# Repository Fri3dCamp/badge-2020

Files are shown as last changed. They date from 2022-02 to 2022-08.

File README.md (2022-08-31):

# Fri3d Badge 2020

This repository contains the hardware design of the [Fri3d Camp](https://fri3d.be/) badge for 2020 / 2022. The project progress can be followed on our [Hackaday.io](https://hackaday.io/project/169741-fri3d-2022-badge) page.

## Blockdiagram

In order to make the documentation easier to use, we've added the block diagram in this repository.

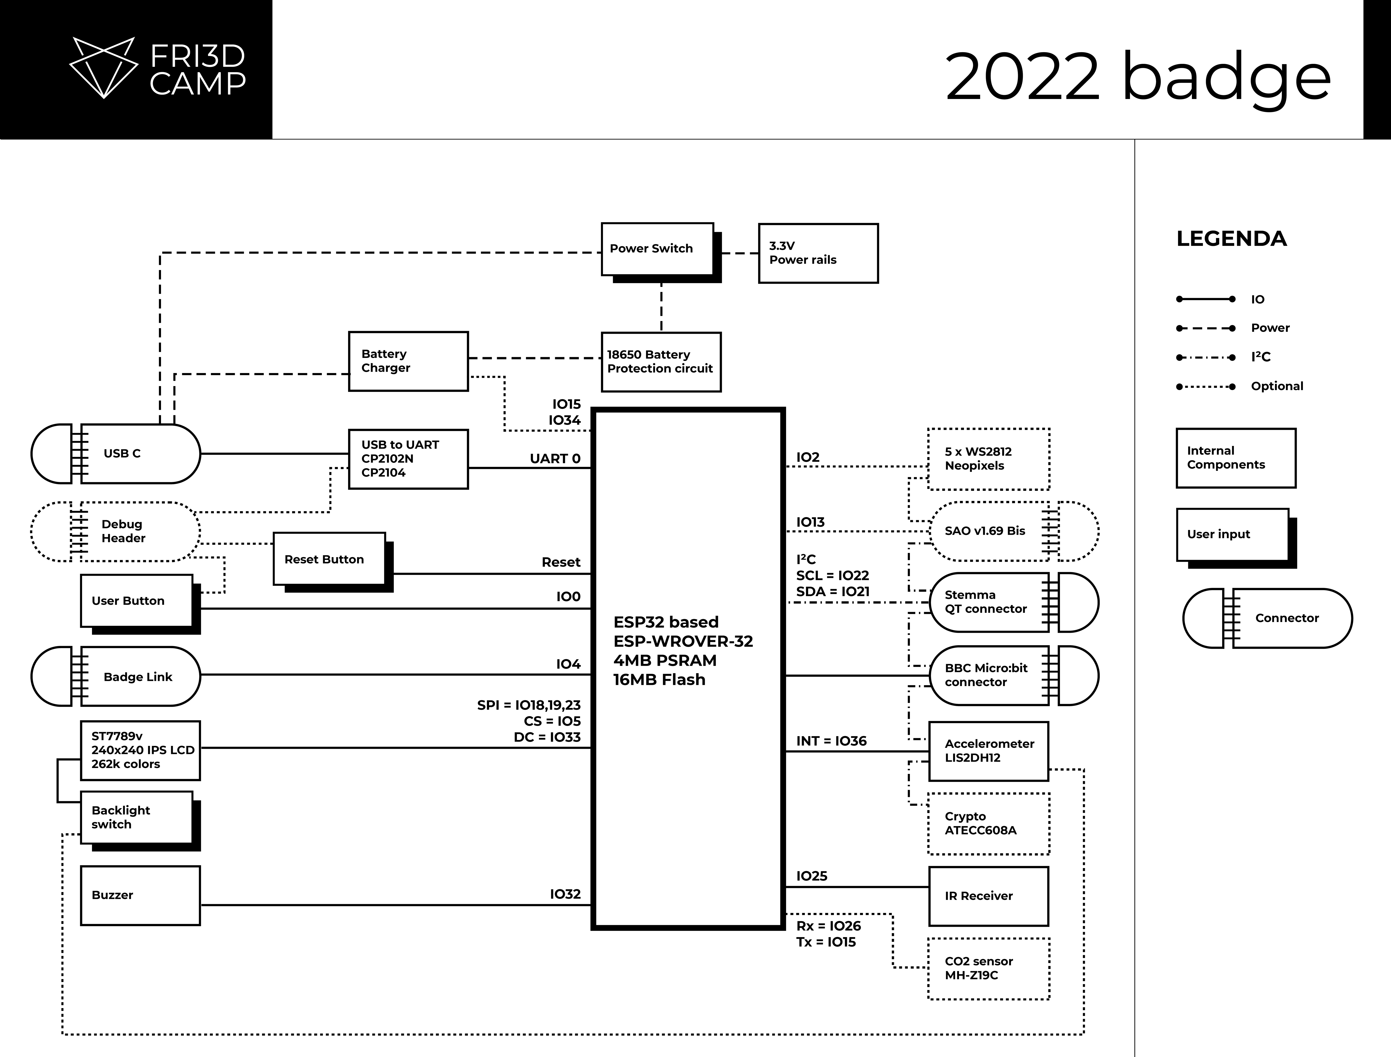
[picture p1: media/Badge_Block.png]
Badge Block Diagram


## REV 00
First prototype to verify the schematic design.

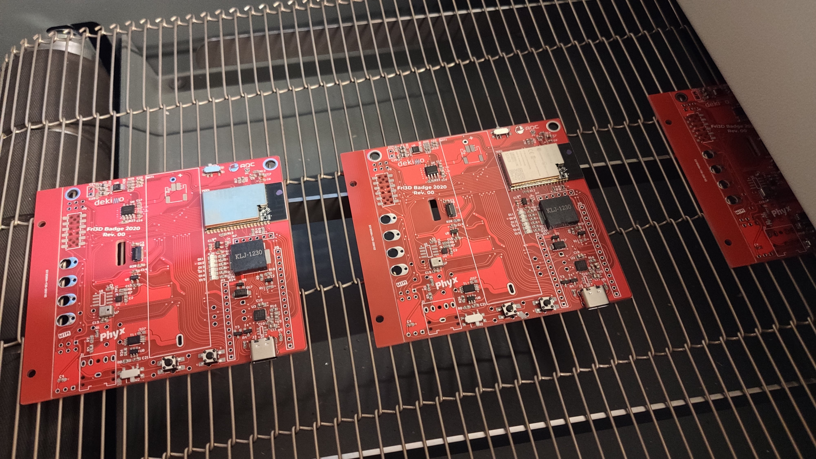
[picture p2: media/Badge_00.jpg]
Badge 00


## REV 01
Moved away from the Adafruit Feather compatible expansion header in favor for the [BBC micro:bit expansion connector](https://tech.microbit.org/hardware/edgeconnector/)

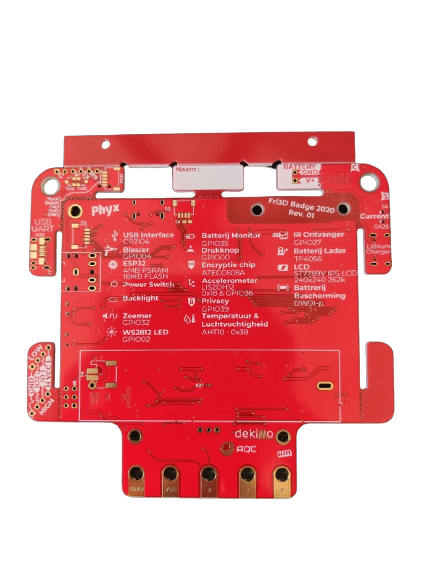
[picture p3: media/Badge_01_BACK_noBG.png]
Badge 01


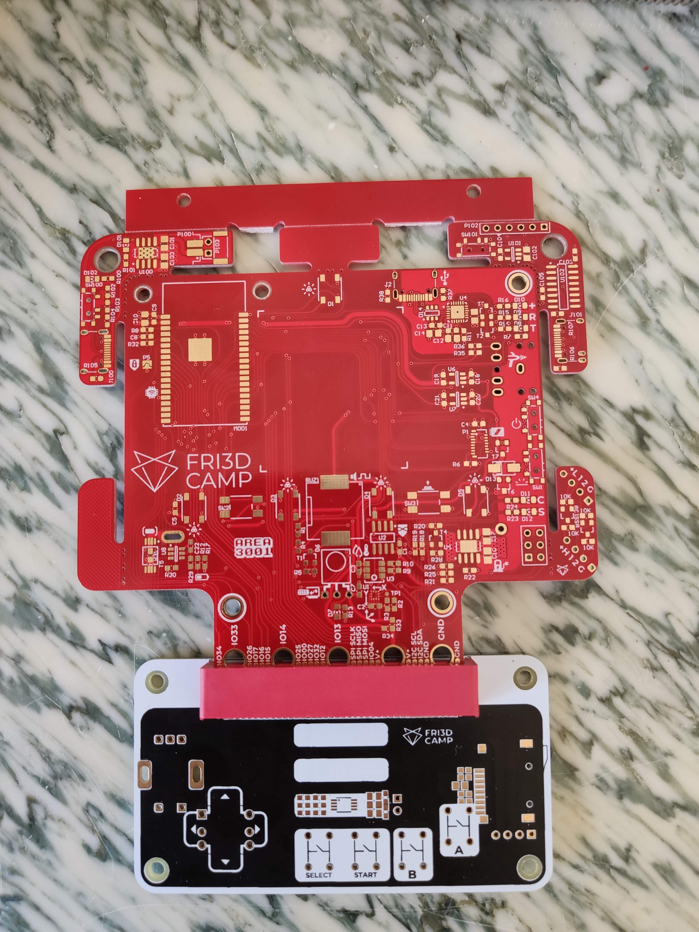
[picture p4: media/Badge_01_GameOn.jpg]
Badge 01 GameOn

Test fit of the badge with the first protoype of the [GameOn](https://github.com/Fri3dCamp/gameon-2020)

## REV 02
Upgraded the micro:bit connector to V2 shape.
This board has the final shape for the badge and has a green soldermask with black silkscreen.

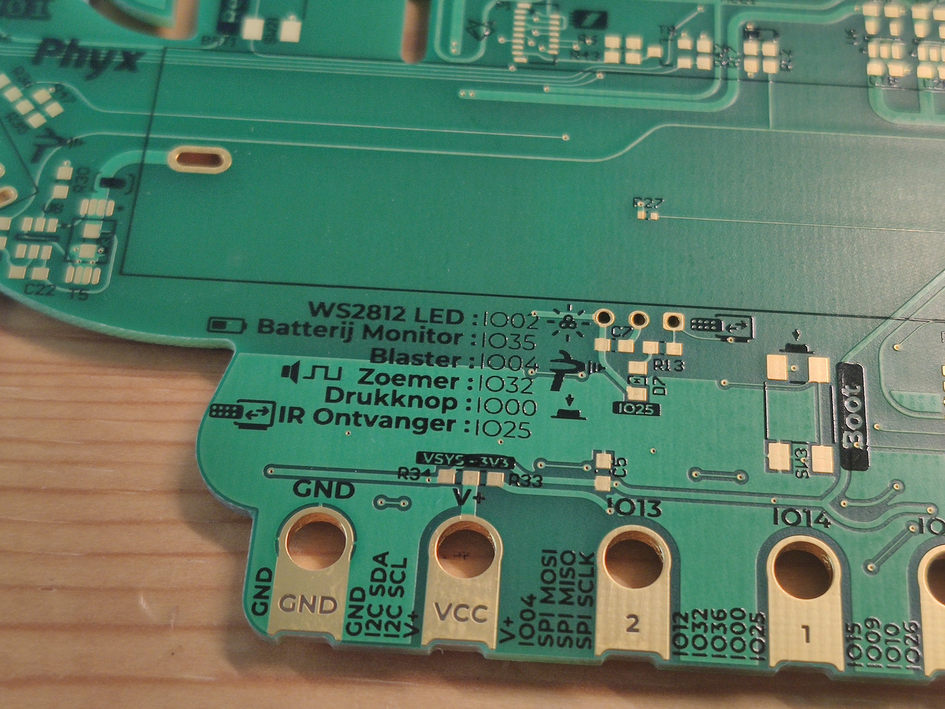
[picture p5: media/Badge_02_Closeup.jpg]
Badge 02 Close up


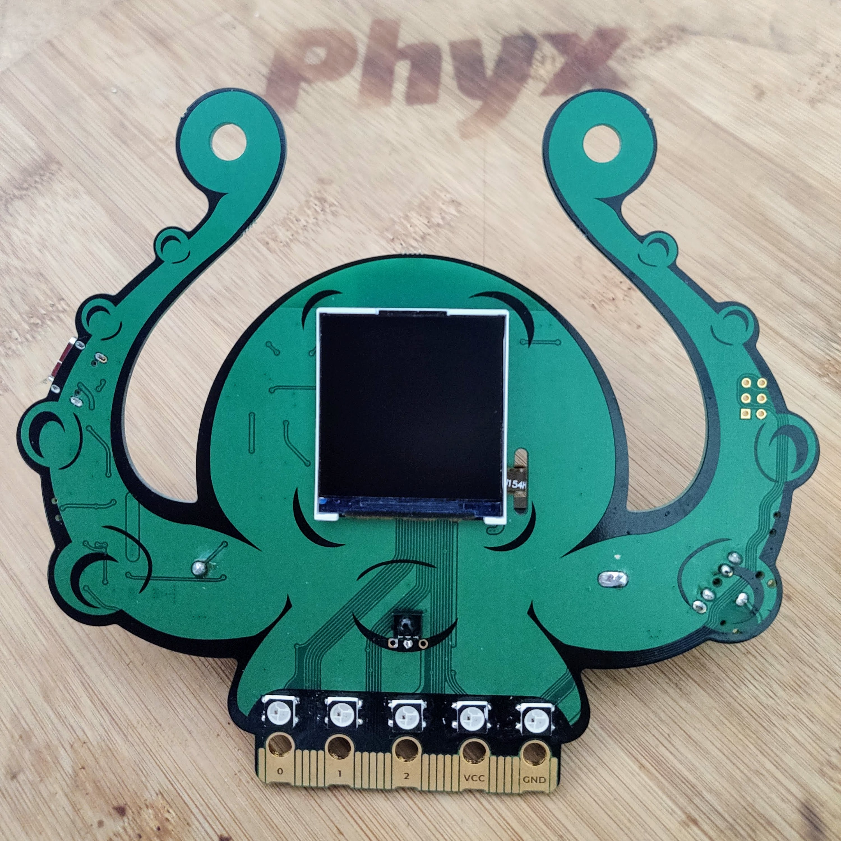
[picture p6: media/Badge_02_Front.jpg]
Badge 02 Close up


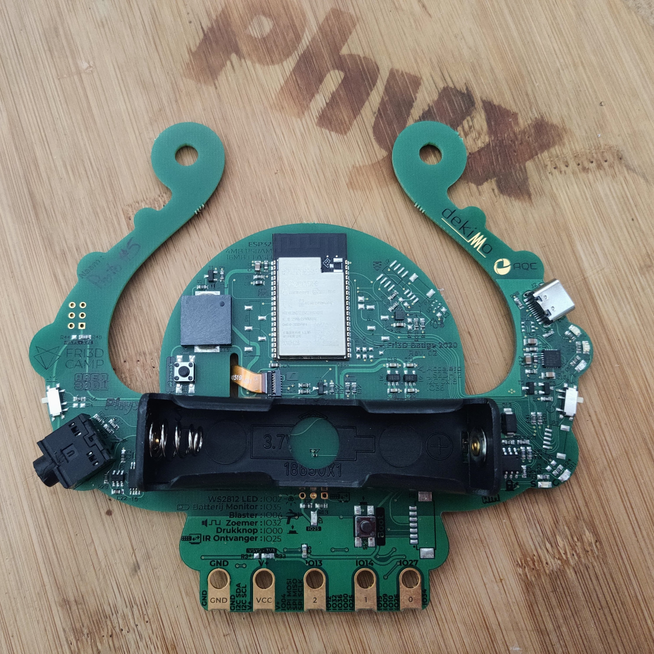
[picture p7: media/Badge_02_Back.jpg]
Badge 02 Close up


## REV 03
The production version of the badge with improvements in the BadgeLink circuit and a change in the LCD backlight button operation. Now the slide switch will either turn the display backlight ON or render it's control to the interrupt pin from the accelerometer allowing for wakeup based on movement for increased battery savings.

## Documentation
In the "media" folder we've added the small infosheet leaflet that's included with the badge as well as the presentation that was given bij Wim Van Gool during the event.

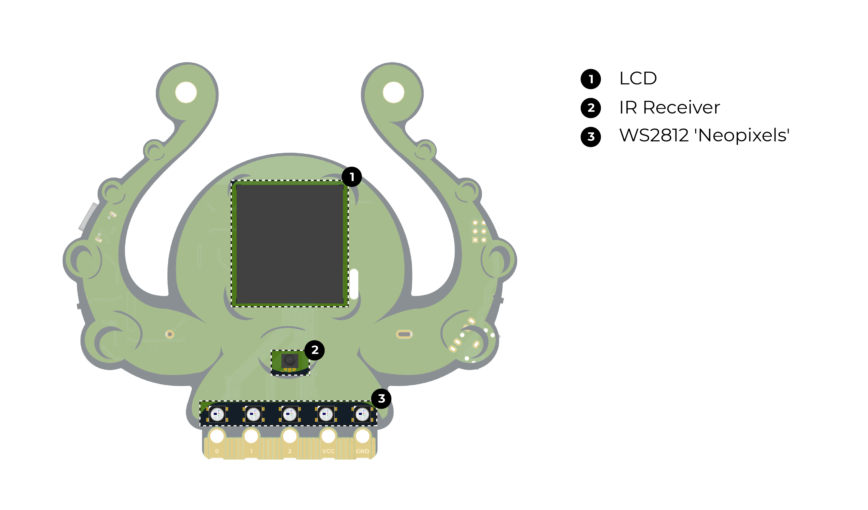
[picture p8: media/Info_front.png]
Badge 03 info front


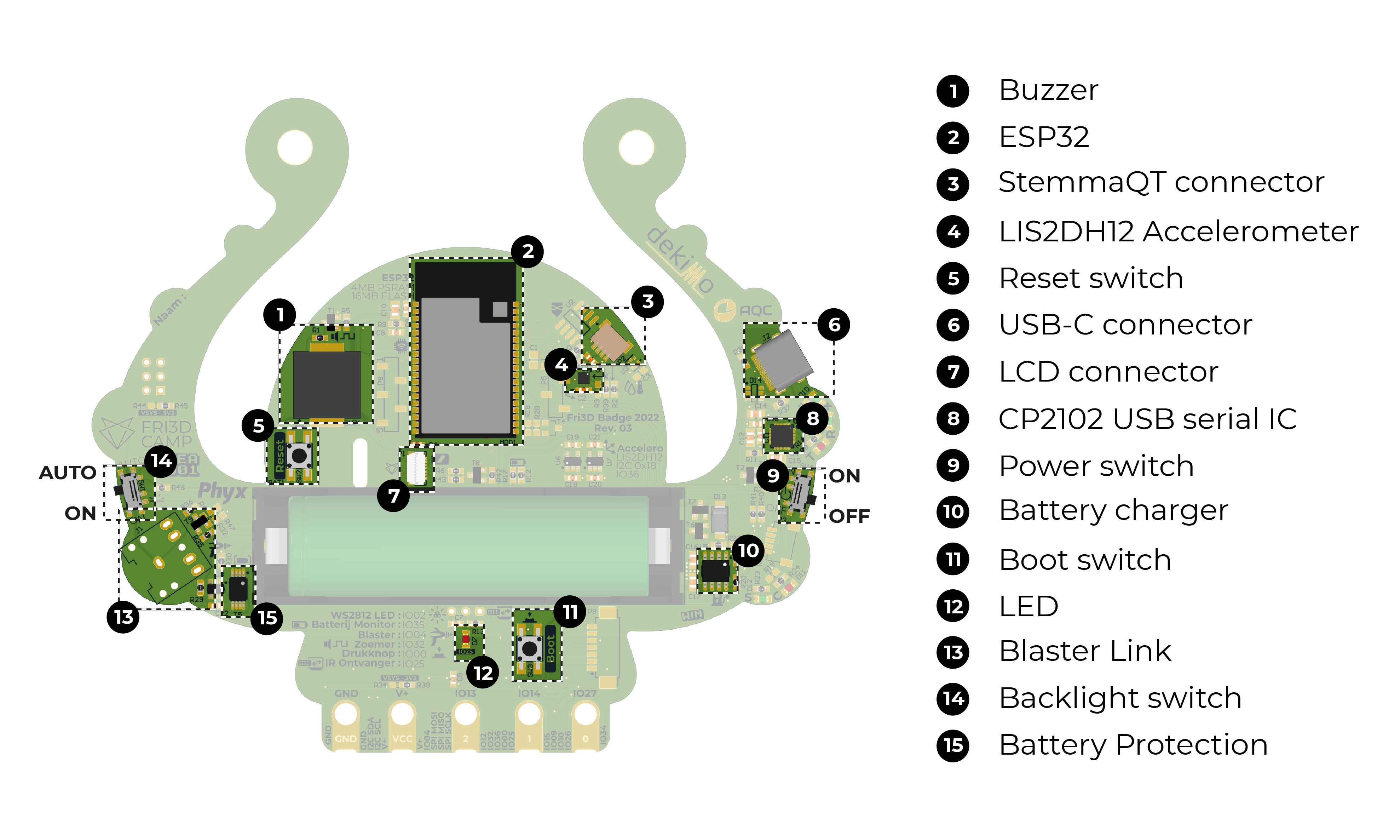
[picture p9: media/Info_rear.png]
Badge 03 info rear


## Hackability

As highlighted in the presentation, the badge has some expansion possibilities.

### CO2 sensor

With the help of P5 and P8 SMD headers [61000413321, 61000513321]( https://www.we-online.com/catalog/en/PHD_2_54_SMT_SOCKET_HEADER_6100XXXXX21) and a 10µF 0805 capacitor, you can add the [MH-Z19C sensor]( https://www.reichelt.com/be/nl/infrarood-co2-sensor-mh-z19c-pin-header-rm-2-54-co2-mh-z19c-ph-p297320.html). Alternatively, there is also room for the [Molex 
53261-0771](https://www.molex.com/molex/products/part-detail/pcb_headers/0532610771) SMD connector on P9 so you can use the [wire mounted variant of the MH-Z19C]( https://www.tinytronics.nl/shop/en/sensors/air/gas/winsen-mh-z19c-co2-sensor-with-cable)
Note that this sensor will only work on 5V so USB power is required. It connects the CO2's serial port to IO26 and IO15 of the ESP32.

### Battery Charger Control

By mounting R18 and R19 with a 100Ω you gain battery charging control. This will allow to read the charger status on GPIO34 and control whether or not the battery should be charging using GPIO15.

### Temperature and Humidity sensor

The [Wurth 2525020210001]( https://www.we-online.com/catalog/en/WSEN-HIDS) temperature and humidity sensor can be mounted on the U3 footprint along with a 100nF 0603 capacitor on C3 for local decoupling.

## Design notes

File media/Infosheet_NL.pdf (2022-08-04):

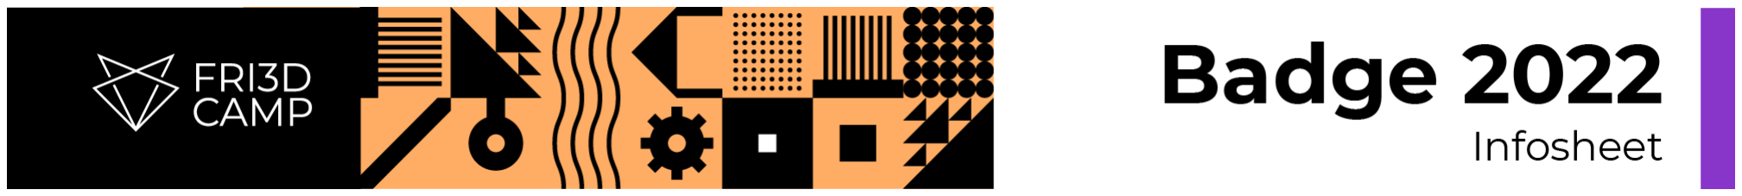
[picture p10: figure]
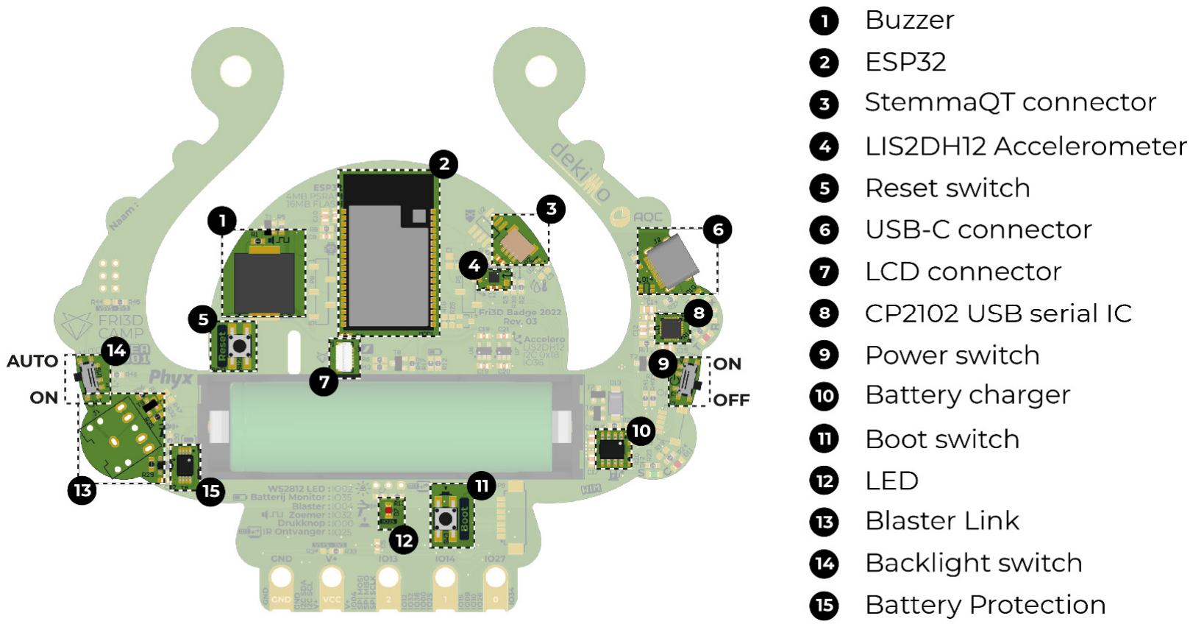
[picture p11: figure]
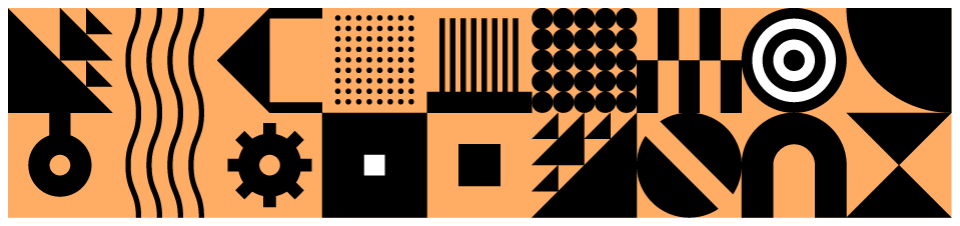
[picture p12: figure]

Wim Van Gool – 20220802 – Badge NL Rev.00 https://github.com/Fri3dCamp/badge-2020https://hackaday.io/project/169741-fri3d-2022-badgehttps://fri3d.be/badge/

Software
De badge is reeds voorzien van software. De meest recente versie kan je steeds terug vinden op https://fri3d.be/badge

Indicatie LEDs
Op de PCB hebben we 5 indicatie-LEDs voorzien: 3 rond het USB-circuit (+, R, T) en 2 bij de batterijlader (S, C).

De “+” geeft aan dat de USB-poort spanning heeft. De “R” en “T” zijn indicatoren voor ontvangen of verzonden data over deze USB.

Voor de batterijlader zijn er groene “S” en rode “C” LEDs. De combinatie van deze 2 LEDs geeft de status weer van de lader.

Status | “C” LED | “S” LED
Batterij is aan het laden | LED aan | LED uit
Batterij is opgeladen | LED uit | LED aan
Temperatuur van de batterij is buiten werkzaam gebied | LED uit | LED uit
Geen batterij aanwezig | LED knippert | LED aan

Overzicht van de functionaliteit

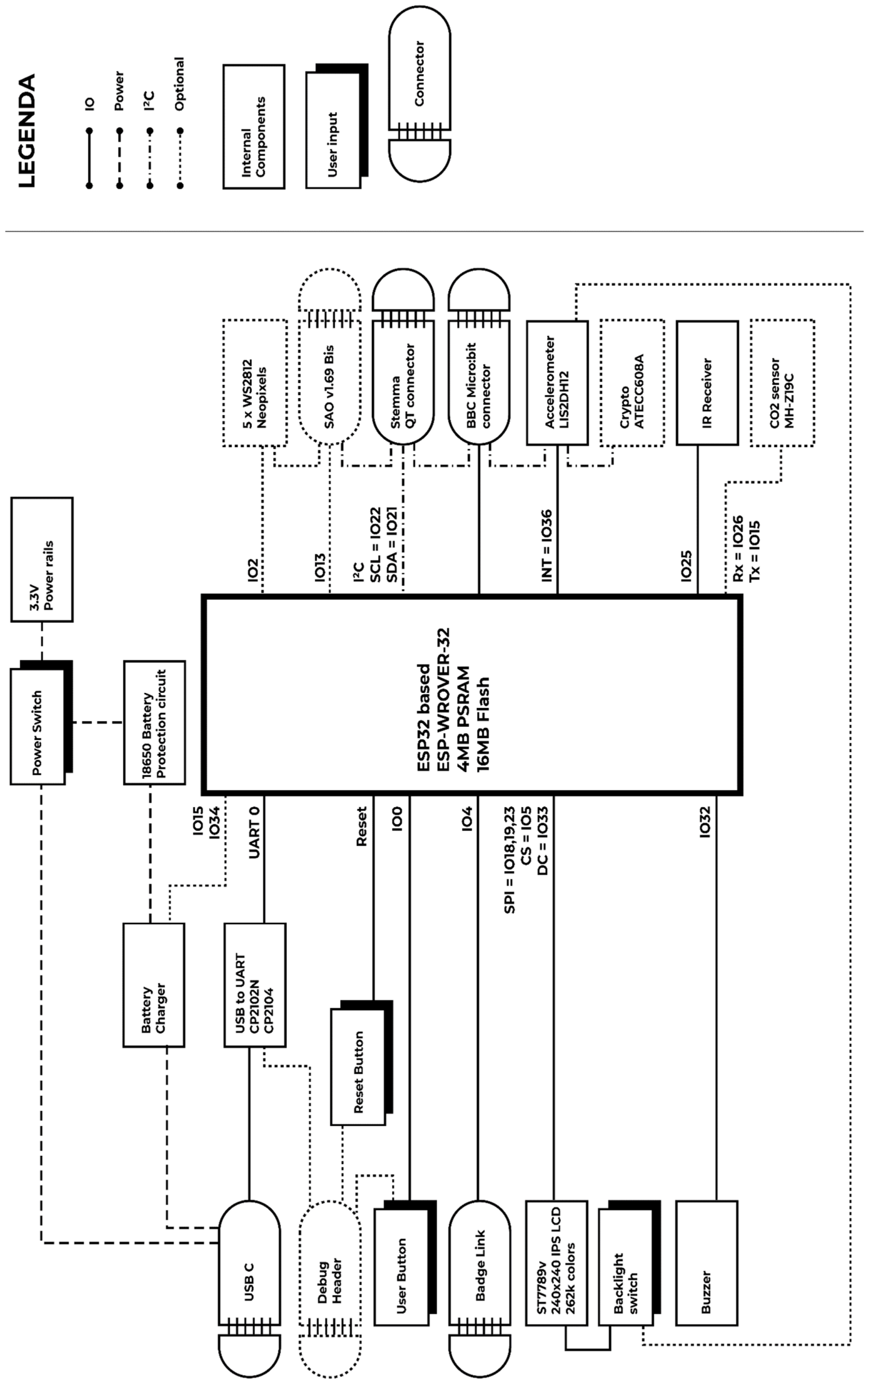
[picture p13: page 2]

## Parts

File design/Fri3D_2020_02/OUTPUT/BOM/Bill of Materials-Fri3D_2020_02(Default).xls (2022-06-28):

Bill of Materials |  |  | Fri3D Badge 2020
Project: |  | Fri3D_2020_02.PrjPcb
Revision: |  | 02
Variant: |  | Default
Creation Date: | 07/01/2022 | 23:19
Print Date: | 2022-03-08 | 14:14:21
Footprint | Comment | LibRef | Designator | Value | Description | Supplier 1 | Supplier Part Number 1 | Supplier 2 | Supplier Part Number 2 | Supplier 3 | Supplier Part Number 3 | Quantity | 750 | 2020-01-26 | order?
BAT_18650_SPRING | 18650 Battery holder with spring | 18650 Battery holder spring CN | BAT1 | 18650_SPRING | 18650 Battery holder spring CN | TaoBao | 39761834568 |  |  |  |  | 1 | 750 | 750 | 0 | LETOP!
CUI_CMT-1203-SMT | 12x12x3mm Piezo Buzzer Transducer 81dB | BUZ # CUI CMT-1203-SMT | BUZ1 | CMT-1203-SMT | BUZ # CUI CMT-1203-SMT | Digi-key | 102-2197-1-ND | LCSC | C409829 | LCSC | C391037 | 1 | 750 | 750 | 0 | LETOP!
C0603_N |  | CAP # 100nF 16V 0603 | C2, C4, C7, C8, C9, C11, C13, C22 | 100nF 16V | CAP # 100nF 16V 0603 | LCSC | C282519 |  |  | Generic | 100nF 16V 0603 X7R | 8 | 6000 | 12000 | 0
C0603_N |  | CAP # 1uF 16V 0603 | C5, C18, C19, C20, C21 | 1uF 16V | CAP # 1uF 16V 0603 | Farnell | 2320814 |  |  | Generic | 1uF 16V 0603 X7R | 5 | 3750 | 8000 | 0
C0805_N |  | CAP # 10uF 10V 0805 | C10, C12, C14, C15, C16, C17 | 10uF 10V | CAP # 10uF 10V 0805 | Farnell | 2320859 | LCSC | C17024 | Generic | 10uF 10V 0805 X7R | 6 | 4500 | 6000 | 0
LED_5050_WS2812B_BLACK | WS2812 based digital RGB LED 5050 Black package | LED # RGB WS2812B-5050 BL | D1, D2, D3, D4, D5 | WS218B 5050 BL | LED # RGB WS2812B-5050 BL | Aliexpress | WS2812B Black 5050 | LCSC | C114586 |  |  | 5 | 3750 | 6000 | 0
VIS_TSOP381x_BENT | IRM-3638N3F14 Infrared Receiver 38 kHz 45° 2.7-5.5V | PHO IR Rx RA | D6 | IRM-3638N3F14 | PHO IR Rx RA | LCSC | C264262 |  |  |  |  | 1 | 750 |  | 750 | LETOP!
LED_0805_RD | Default 0805 Red LED | LED # Red 0805 | D7, D8, D11 |  | LED # Red 0805 | Farnell | 2099236 |  |  |  |  | 3 | 2250 | 3000 | 0
LED_0805_GR | Default 0805 Green LED | LED # Green 0805 | D9, D10, D12 |  | LED # Green 0805 | Farnell | 2099239 |  |  |  |  | 3 | 2250 | 3000 | 0
SMA_AC | MBRA210LT3G Schottky Power Rectifier, 2A, 10V | Schottky # MBRA210LT3G | D13 | MBRA210LT3G | Schottky # MBRA210LT3G | LCSC | C145190 |  |  |  |  | 1 | 750 | 800 | 0
HRO_TYPE-C-31-M-12 | USB 2.0 C Reversible Receptacle Horizontal | USB # C 2.0 RCPT TYPE-C-31-M-12 | J2 | TYPE-C-31-M-12 | USB # C 2.0 RCPT TYPE-C-31-M-12 | China | HRO TYPE-C-31-M-12 | LCSC | C165948 | LCSC ALT | C167321 / C319148 | 1 | 750 | 1000 | 0
ESP-WROVER-32 | ESP-32 based ESP-WROVER-32 | WiFi # MOD ESP-WROVER-32 | MOD1 | ESP-WROVER-32 | WiFi # MOD ESP-WROVER-32 | Espressif | ESP-WROVER-32 |  |  |  |  | 1 | 750 | 800 | 0
FPC_AFE03-S15FMA-1H | Bottom contact FPC 0.3mm pitch 15 contacts | FPC # 15 Bottom 0.3mm AFE03-S15FMA-1H | P1 | AFE03-S15FMA-1H | FPC # 15 Bottom 0.3mm AFE03-S15FMA-1H | LCSC | C262541 |  |  |  |  | 1 | 750 | 800 | 0
MicroBIT_V2_PCB | MicroBit PCB connector | MicroBit # PCB part | P7 |  | MicroBit # PCB part | NO PART |  |  |  |  |  | 1 | 750 | 10000 | 0
R0603_N |  | RES # 1K2 0603 | R1, R11, R13, R14, R15, R16, R22, R23, R24, R30 | 1K2 | RES # 1K2 0603 | Farnell | 2446592 |  |  | Generic | 1K2 1% 0603 | 10 | 7500 | 10000 | 0
R0603_N |  | RES # 100K 0603 | R2, R5, R12, R17, R25, R26, R42 | 100K | RES # 100K 0603 |  |  |  |  | Generic | 100K 1% 0603 | 7 | 5250 |  | 5250 | LETOP!
R0603_N |  | RES # 100R 0603 | R6, R29, R39, R40, R41, R43, R46 | 100R | RES # 100R 0603 | Farnell | 2446544 |  |  | Generic | 100R 1% 0603 | 7 | 5250 | 5000 | 250 | LETOP!
R0603_N |  | RES # 5K1 0603 | R7, R8, R9, R10, R20, R21, R35, R36, R37, R38, R47 | 5K1 | RES # 5K1 0603 | Farnell | 2845922 | LCSC | C112314 | Generic | 5K1 1% 0603 | 11 | 8250 | 10000 | 0
R0402 |  | NTC # 10K 0402 | R27 | 10K | NTC # 10K 0402 | LCSC | C209959 | LCSC | C98099 |  |  | 1 | 750 |  | 750 | LETOP!
R0603_N |  | RES # 0R 0603 | R33, R45 | 0R | RES # 0R 0603 | Farnell | 2447743 | LCSC | 5000 | Generic | 0R 1% 0603 | 2 | 1500 |  | 1500 | LETOP!
WE_450404015514 | WS-SLSU Mini slide switch 1P2T SMD | SW # 1P2T WS-SLSU mini slide 6,7 x 2,7 mm | SW1, SW4 | 450404015514 | SW # 1P2T WS-SLSU mini slide 6,7 x 2,7 mm | Digi-key | 732-13665-1-ND | LCSC | C431540 |  |  | 2 | 1500 | 3000 | 0
WE_430181038816 | 4.5x4.5mm tact SMD H3,8mm | SW # TACT small 4.5x4.5mm SMD WS-TASV | SW2, SW3 | 430181038816 | SW # TACT small 4.5x4.5mm SMD WS-TASV | Wurth | 430181038816 | Mouser | 710-430181038816 | LCSC | C174049 | 2 | 1500 | 2000 | 0
SOT23-3 | 0.2A N-Ch MOSFET Vgs 3.2 | BSS138 N-Ch MOSFET 0.2A 3.2Vgs 60Vds | T1, T2, T3, T8 | BSS138 | BSS138 N-Ch MOSFET 0.2A 3.2Vgs 60Vds | Farnell | 2432717 | LCSC | C426569 |  |  | 4 | 3000 | 3000 | 0 | LETOP!
TSSOP_8_65P | Dual N-Ch MOSFET Common Drain | FS8205A Dual N-Ch common Drain for DW01-P | T5 | FS8205A | FS8205A Dual N-Ch common Drain for DW01-P | AliExpress | FS8205A | LCSC | C16052 |  |  | 1 | 750 | 800 | 0
SOT23-3 | -2.3A -20V P-Ch MOSFET Vgs -1V | SL2301 P-Ch MOSFET -2.3A -20Vds | T6, T7 | SL2301 | SL2301 P-Ch MOSFET -2.3A -20Vds | LCSC | C181086 |  |  |  |  | 2 | 1500 | 800 | 700 | LETOP!
STM_LGA12_2x2 | 3-Axis, ±2 g/±4 g/±8 g/±16 g Digital Accelerometer | ACCELERO # LIS2DH12 | U1 | LIS2DH12 | ACCELERO # LIS2DH12 | LCSC | C110926 |  |  |  |  | 1 | 750 | 800 | 0
QFN_24 | USB to UART 3.3-5V | CP2102N # QFN24 USB UART | U4 | CP2102N-A01-GQFN24 | CP2102N # QFN24 USB UART | Farnell | 2577278 | Digi-key | 336-3693-ND |  |  | 1 | 750 | 800 | 0
SOIC_N_8_TH | Single Cell LiIon charger max 1A | CHG # TP4056 LiIon 1A | U5 | TP4056 | CHG # TP4056 LiIon 1A | Aliexpress | TP4056 | LCSC | C382139 |  |  | 1 | 750 | 800 | 0
SOT23-5 | 3V3 LDO 700mA 50mV | LDO # 3V3 XC6210B33 | U6, U7 | XC6210B332MR | LDO # 3V3 XC6210B33 | Farnell | 1057803 | LCSC | C47719 |  |  | 2 | 1500 | 3000 | 0
SOT23-6 | DW01-P single cell lithium protection | PWR # DW01-P Lithium protection | U8 | DW01-P | PWR # DW01-P Lithium protection | Aliexpress | DW01-P | LCSC | C181096 |  |  | 1 | 750 | 800 | 0
 |  |  |  |  |  |  |  |  |  |  |  | 93
Approved |  | Notes

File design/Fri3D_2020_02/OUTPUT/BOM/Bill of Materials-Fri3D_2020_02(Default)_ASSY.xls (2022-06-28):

Bill of Materials |  | Fri3D Badge 2020
Project: | Fri3D_2020_02.PrjPcb
Revision: | 02
Variant: | Default
Footprint | LibRef | Designator | Value | Description | Qty | x10 | Location
BAT_18650_SPRING | 18650 Battery holder spring CN | BAT1 | 18650_SPRING | 18650 Battery holder spring CN | 1 | 10
CUI_CMT-1203-SMT | BUZ # CUI CMT-1203-SMT | BUZ1 | CMT-1203-SMT | BUZ # CUI CMT-1203-SMT | 1 | 10
C0603_N | CAP # 100nF 16V 0603 | C2, C4, C7, C8, C9, C11, C13, C22 | 100nF 16V | CAP # 100nF 16V 0603 | 8 | 80
C0603_N | CAP # 1uF 16V 0603 | C5, C18, C19, C20, C21 | 1uF 16V | CAP # 1uF 16V 0603 | 5 | 50
C0805_N | CAP # 10uF 10V 0805 | C10, C12, C14, C15, C16, C17 | 10uF 10V | CAP # 10uF 10V 0805 | 6 | 60
LED_5050_WS2812B_BLACK | LED # RGB WS2812B-5050 BL | D1, D2, D3, D4, D5 | WS218B 5050 BL | LED # RGB WS2812B-5050 BL | 5 | 50
VIS_TSOP381x_BENT | PHO IR Rx RA | D6 | IRM-3638N3F14 | PHO IR Rx RA | 1 | 10
LED_0805_RD | LED # Red 0805 | D7, D8, D11 |  | LED # Red 0805 | 3 | 30
LED_0805_GR | LED # Green 0805 | D9, D10, D12 |  | LED # Green 0805 | 3 | 30
SMA_AC | Schottky # MBRA210LT3G | D13 | MBRA210LT3G | Schottky # MBRA210LT3G | 1 | 10
HRO_TYPE-C-31-M-12 | USB # C 2.0 RCPT TYPE-C-31-M-12 | J2 | TYPE-C-31-M-12 | USB # C 2.0 RCPT TYPE-C-31-M-12 | 1 | 10
ESP-WROVER-32 | WiFi # MOD ESP-WROVER-32 | MOD1 | ESP-WROVER-32 | WiFi # MOD ESP-WROVER-32 | 1 | 10
FPC_AFE03-S15FMA-1H | FPC # 15 Bottom 0.3mm AFE03-S15FMA-1H | P1 | AFE03-S15FMA-1H | FPC # 15 Bottom 0.3mm AFE03-S15FMA-1H | 1 | 10
MicroBIT_V2_PCB | MicroBit # PCB part | P7 |  | MicroBit # PCB part | 1 | 10
R0603_N | RES # 1K2 0603 | R1, R11, R13, R14, R15, R16, R22, R23, R24, R30 | 1K2 | RES # 1K2 0603 | 10 | 100
R0603_N | RES # 100K 0603 | R2, R5, R12, R17, R25, R26, R42 | 100K | RES # 100K 0603 | 7 | 70
R0603_N | RES # 100R 0603 | R6, R29, R39, R40, R41, R43, R46 | 100R | RES # 100R 0603 | 7 | 70
R0603_N | RES # 5K1 0603 | R7, R8, R9, R10, R20, R21, R35, R36, R37, R38, R47 | 5K1 | RES # 5K1 0603 | 11 | 110
R0402 | NTC # 10K 0402 | R27 | 10K | NTC # 10K 0402 | 1 | 10
R0603_N | RES # 0R 0603 | R33, R45 | 0R | RES # 0R 0603 | 2 | 20
WE_450404015514 | SW # 1P2T WS-SLSU mini slide 6,7 x 2,7 mm | SW1, SW4 | 450404015514 | SW # 1P2T WS-SLSU mini slide 6,7 x 2,7 mm | 2 | 20
WE_430181038816 | SW # TACT small 4.5x4.5mm SMD WS-TASV | SW2, SW3 | 430181038816 | SW # TACT small 4.5x4.5mm SMD WS-TASV | 2 | 20
SOT23-3 | BSS138 N-Ch MOSFET 0.2A 3.2Vgs 60Vds | T1, T2, T3, T8 | BSS138 | BSS138 N-Ch MOSFET 0.2A 3.2Vgs 60Vds | 4 | 40
TSSOP_8_65P | FS8205A Dual N-Ch common Drain for DW01-P | T5 | FS8205A | FS8205A Dual N-Ch common Drain for DW01-P | 1 | 10
SOT23-3 | SL2301 P-Ch MOSFET -2.3A -20Vds | T6, T7 | SL2301 | SL2301 P-Ch MOSFET -2.3A -20Vds | 2 | 20
STM_LGA12_2x2 | ACCELERO # LIS2DH12 | U1 | LIS2DH12 | ACCELERO # LIS2DH12 | 1 | 10
QFN_24 | CP2102N # QFN24 USB UART | U4 | CP2102N-A01-GQFN24 | CP2102N # QFN24 USB UART | 1 | 10
SOIC_N_8_TH | CHG # TP4056 LiIon 1A | U5 | TP4056 | CHG # TP4056 LiIon 1A | 1 | 10
SOT23-5 | LDO # 3V3 XC6210B33 | U6, U7 | XC6210B332MR | LDO # 3V3 XC6210B33 | 2 | 20
SOT23-6 | PWR # DW01-P Lithium protection | U8 | DW01-P | PWR # DW01-P Lithium protection | 1 | 10
 |  |  |  |  | 93 | 930
Approved | Notes

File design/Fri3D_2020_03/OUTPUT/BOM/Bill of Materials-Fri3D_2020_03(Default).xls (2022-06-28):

Bill of Materials |  |  | Fri3D Badge 2022
Project: |  | Fri3D_2020_03.PrjPcb
Revision: |  | 03
Variant: |  | Default
Creation Date: | 06/06/2022 | 20:56
Print Date: | 2022-06-10 | 20:35:48
Footprint | Comment | LibRef | Designator | Value | Description | Supplier 1 | Supplier Part Number 1 | Supplier 2 | Supplier Part Number 2 | Supplier 3 | Supplier Part Number 3 | Quantity | 750
BAT_18650_SPRING | 18650 Battery holder with spring | 18650 Battery holder spring CN | BAT1 | 18650_SPRING | 18650 Battery holder spring CN | TaoBao | 39761834568 |  |  |  |  | 1 | 750
CUI_CMT-1203-SMT | 12x12x3mm Piezo Buzzer Transducer 81dB | BUZ # CUI CMT-1203-SMT | BUZ1 | CMT-1203-SMT | BUZ # CUI CMT-1203-SMT | Digi-key | 102-2197-1-ND | LCSC | C409829 | LCSC | C391037 | 1 | 750
C0603_N |  | CAP # 100nF 16V 0603 | C2, C4, C6, C7, C8, C9, C11, C13, C22 | 100nF 16V | CAP # 100nF 16V 0603 | LCSC | C282519 |  |  | Generic | 100nF 16V 0603 X7R | 9 | 6750
C0603_N |  | CAP # 1uF 16V 0603 | C5, C18, C19, C20, C21 | 1uF 16V | CAP # 1uF 16V 0603 | Farnell | 2320814 |  |  | Generic | 1uF 16V 0603 X7R | 5 | 3750
C0805_N |  | CAP # 10uF 10V 0805 | C10, C12, C14, C15, C16, C17 | 10uF 10V | CAP # 10uF 10V 0805 | Farnell | 2320859 | LCSC | C17024 | Generic | 10uF 10V 0805 X7R | 6 | 4500
LED_5050_WS2812B_BLACK | WS2812 based digital RGB LED 5050 Black package | LED # RGB WS2812B-5050 BL | D1, D2, D3, D4, D5 | WS218B 5050 BL | LED # RGB WS2812B-5050 BL | Aliexpress | WS2812B Black 5050 | LCSC | C114586 |  |  | 5 | 3750
LED_0805_RD | Default 0805 Red LED | LED # Red 0805 | D7, D8, D11 |  | LED # Red 0805 | Farnell | 2099236 |  |  |  |  | 3 | 2250
LED_0805_GR | Default 0805 Green LED | LED # Green 0805 | D9, D10, D12 |  | LED # Green 0805 | Farnell | 2099239 |  |  |  |  | 3 | 2250
SMA_AC | MBRA210LT3G Schottky Power Rectifier, 2A, 10V | Schottky # MBRA210LT3G | D13 | MBRA210LT3G | Schottky # MBRA210LT3G | LCSC | C145190 |  |  |  |  | 1 | 750
CHAU_ZIRM-5042B-42-Z2 | ZIRM-5042B-42-Z2 Infrared Receiver 38 kHz 45° 2.7-5.5V 940nm | PHO # IR Rx 940nm ZIRM-5042B-42-Z2 | D15 | ZIRM-5042B-42-Z2 | PHO # IR Rx 940nm ZIRM-5042B-42-Z2 | LCSC | C575386 |  |  |  |  | 1 | 750
HRO_TYPE-C-31-M-12 | USB 2.0 C Reversible Receptacle Horizontal | USB # C 2.0 RCPT TYPE-C-31-M-12 | J2 | TYPE-C-31-M-12 | USB # C 2.0 RCPT TYPE-C-31-M-12 | China | HRO TYPE-C-31-M-12 | LCSC | C165948 | LCSC ALT | C167321 / C319148 | 1 | 750
ESP-WROVER-32 | ESP-32 based ESP-WROVER-32 | WiFi # MOD ESP-WROVER-32 | MOD1 | ESP-WROVER-32 | WiFi # MOD ESP-WROVER-32 | Espressif | ESP-WROVER-32 |  |  |  |  | 1 | 750
FPC_AFE03-S15FMA-1H | Bottom contact FPC 0.3mm pitch 15 contacts | FPC # 15 Bottom 0.3mm AFE03-S15FMA-1H | P1 | AFE03-S15FMA-1H | FPC # 15 Bottom 0.3mm AFE03-S15FMA-1H | LCSC | C262541 |  |  |  |  | 1 | 750
WE_665104131822 | Header 1.0mm RA Shrouded 4 | HDR # RA SHR 1.0mm 4way - 665104131822 | P2 | 665104131822 | HDR # RA SHR 1.0mm 4way - 665104131822 | Wurth | 665104131822 | Mouser | 710-665104131822 |  |  | 1 | 750
MicroBIT_V2_PCB | MicroBit PCB connector | MicroBit # PCB part | P7 |  | MicroBit # PCB part | NO PART |  |  |  |  |  | 1 | 750
R0603_N |  | RES # 1K2 0603 | R1, R11, R13, R14, R15, R16, R22, R23, R24, R30 | 1K2 | RES # 1K2 0603 | Farnell | 2446592 |  |  | Generic | 1K2 1% 0603 | 10 | 7500
R0603_N |  | RES # 5K1 0603 | R2, R7, R8, R9, R10, R20, R21, R35, R36, R37, R38 | 5K1 | RES # 5K1 0603 | Farnell | 2845922 | LCSC | C112314 | Generic | 5K1 1% 0603 | 11 | 8250
R0603_N |  | RES # 100K 0603 | R5, R12, R17, R25, R26, R42 | 100K | RES # 100K 0603 |  |  |  |  | Generic | 100K 1% 0603 | 6 | 4500
R0603_N |  | RES # 100R 0603 | R6, R29, R39, R40, R41, R43, R46 | 100R | RES # 100R 0603 | Farnell | 2446544 |  |  | Generic | 100R 1% 0603 | 7 | 5250
R0402 |  | NTC # 10K 0402 | R27 | 10K | NTC # 10K 0402 | LCSC | C209959 | LCSC | C98099 |  |  | 1 | 750
R0603_N |  | RES # 0R 0603 | R33, R45 | 0R | RES # 0R 0603 | Farnell | 2447743 | LCSC | C95177 | Generic | 0R 1% 0603 | 2 | 1500
WE_450404015514 | WS-SLSU Mini slide switch 1P2T SMD | SW # 1P2T WS-SLSU mini slide 6,7 x 2,7 mm | SW1, SW4 | 450404015514 | SW # 1P2T WS-SLSU mini slide 6,7 x 2,7 mm | Digi-key | 732-13665-1-ND | LCSC | C431540 |  |  | 2 | 1500
WE_430181038816 | 4.5x4.5mm tact SMD H3,8mm | SW # TACT small 4.5x4.5mm SMD WS-TASV | SW2, SW3 | 430181038816 | SW # TACT small 4.5x4.5mm SMD WS-TASV | Wurth | 430181038816 | Mouser | 710-430181038816 | LCSC | C174049 | 2 | 1500
SOT23-3 | 0.2A N-Ch MOSFET Vgs 3.2 | BSS138 N-Ch MOSFET 0.2A 3.2Vgs 60Vds | T1, T2, T3, T8, T9 | BSS138 | BSS138 N-Ch MOSFET 0.2A 3.2Vgs 60Vds | Farnell | 2432717 | LCSC | C426569 |  |  | 5 | 3750
TSSOP_8_65P | Dual N-Ch MOSFET Common Drain | FS8205A Dual N-Ch common Drain for DW01-P | T5 | FS8205A | FS8205A Dual N-Ch common Drain for DW01-P | AliExpress | FS8205A | LCSC | C16052 |  |  | 1 | 750
SOT23-3 | -2.3A -20V P-Ch MOSFET Vgs -1V | SL2301 P-Ch MOSFET -2.3A -20Vds | T6, T7 | SL2301 | SL2301 P-Ch MOSFET -2.3A -20Vds | LCSC | C181086 |  |  |  |  | 2 | 1500
STM_LGA12_2x2 | 3-Axis, ±2 g/±4 g/±8 g/±16 g Digital Accelerometer | ACCELERO # LIS2DH12 | U1 | LIS2DH12 | ACCELERO # LIS2DH12 | LCSC | C110926 |  |  |  |  | 1 | 750
QFN_24 | USB to UART 3.3-5V | CP2102N # QFN24 USB UART | U4 | CP2102N-A01-GQFN24 | CP2102N # QFN24 USB UART | Farnell | 2577278 | Digi-key | 336-3693-ND |  |  | 1 | 750
SOIC_N_8_TH | Single Cell LiIon charger max 1A | CHG # TP4056 LiIon 1A | U5 | TP4056 | CHG # TP4056 LiIon 1A | Aliexpress | TP4056 | LCSC | C382139 |  |  | 1 | 750
SOT23-5 | 3V3 LDO 700mA 50mV | LDO # 3V3 XC6210B33 | U6, U7 | XC6210B332MR | LDO # 3V3 XC6210B33 | Farnell | 1057803 | LCSC | C47719 |  |  | 2 | 1500
SOT23-6 | DW01-P single cell lithium protection | PWR # DW01-P Lithium protection | U8 | DW01-P | PWR # DW01-P Lithium protection | Aliexpress | DW01-P | LCSC | C181096 |  |  | 1 | 750
 |  |  |  |  |  |  |  |  |  |  |  | 95
Approved |  | Notes

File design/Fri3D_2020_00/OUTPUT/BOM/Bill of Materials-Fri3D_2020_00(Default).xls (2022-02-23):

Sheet: BOM Report
Bill of Materials |  |  | Fri3D Badge 2020
Project: |  | Fri3D_2020_00.PrjPcb
Revision: |  | 00
Variant: |  | Default
Creation Date: | 31/12/2019 | 11:32
Print Date: | 2019-12-31 | 12:15:19
Footprint | Comment | LibRef | Designator | Value | Description | Supplier 1 | Supplier Part Number 1 | Supplier 2 | Supplier Part Number 2 | Supplier 3 | Supplier Part Number 3 | Quantity
BAT_18650_SPRING | 18650 Battery holder with spring | 18650 Battery holder spring CN | BAT1 | 18650_SPRING | 18650 Battery holder spring CN | TaoBao | 39761834568 |  |  |  |  | 1
CUI_CMT-1203-SMT | 12x12x3mm Piezo Buzzer Transducer 81dB | BUZ # CUI CMT-1203-SMT | BUZ1 | CMT-1203-SMT | BUZ # CUI CMT-1203-SMT | Digi-key | 102-2197-1-ND | Aliexpress | KLJ-1230 | LCSC | C391037 | 1
C0603_N |  | CAP # 100nF 16V 0603 | C1, C2, C3, C4, C5, C6, C8, C10, C19, C21 | 100nF 16V | CAP # 100nF 16V 0603 |  |  |  |  | Generic | 100nF 16V 0603 X7R | 10
C0805_N |  | CAP # 10uF 10V 0805 | C7, C9, C11, C16, C17, C18, C26 | 10uF 10V | CAP # 10uF 10V 0805 | Farnell | 2320859 |  |  | Generic | 10uF 10V 0805 X7R | 7
C0603_N |  | CAP # 1uF 16V 0603 | C12, C13, C14, C15, C20 | 1uF 16V | CAP # 1uF 16V 0603 | Farnell | 2320814 |  |  | Generic | 1uF 16V 0603 X7R | 5
C0603_N |  | CAP # 100nF 50V 0603 | C22, C23 | 100nF 50V | CAP # 100nF 50V 0603 | Farnell | 1759122 |  |  | Generic | 100nF 50V 0603 X7R | 2
C0603_N |  | CAP # 1nF 16V 0603 | C24, C25 | 1nF 16V | CAP # 1nF 16V 0603 |  |  |  |  | Generic | 1nF 16V 0603 X7R | 2
C0603_N |  | CAP # 1uF 50V 0603 | C27 | 1uF 50V | CAP # 1uF 50V 0603 | Farnell | 2112858 |  |  | Generic | 1uF 50V 0603 X7R | 1
LED_5050_WS2812B_BLACK | WS2812 based digital RGB LED 5050 Black package | LED # RGB WS2812B-5050 BL | D2, D3, D4, D5 | WS218B 5050 BL | LED # RGB WS2812B-5050 BL | Aliexpress | WS2812B Black 5050 | LCSC | C114586 |  |  | 4
VIS_TSOP381x_BENT | IRM-3638N3F14 Infrared Receiver 38 kHz 45° 2.7-5.5V | PHO IR Rx RA | D6 | IRM-3638N3F14 | PHO IR Rx RA | LCSC | C264262 |  |  |  |  | 1
LED_0805_RD | Default 0805 Red LED | LED # Red 0805 | D11, D12, D16 |  | LED # Red 0805 | Farnell | 2099236 |  |  |  |  | 3
LED_0805_GR | Default 0805 Green LED | LED # Green 0805 | D13, D15 |  | LED # Green 0805 | Farnell | 2099239 |  |  |  |  | 2
LED_0805_BL | Default 0805 Blue LED | LED # Blue 0805 | D14 |  | LED # Blue 0805 | Farnell | 2217980 |  |  |  |  | 1
SMA_AC | MBRA210LT3G Schottky Power Rectifier, 2A, 10V | Schottky # MBRA210LT3G | D17 | MBRA210LT3G | Schottky # MBRA210LT3G | LCSC | C145190 |  |  |  |  | 1
L0805 |  | FER # 600R 2A 0805 0R10 | F1, F2 | 2A 0R1 | FER # 600R 2A 0805 0R10 | Farnell | 1838838 |  |  |  |  | 2
HRO_TYPE-C-31-M-12 | USB 2.0 C Reversible Receptacle Horizontal | USB # C 2.0 RCPT TYPE-C-31-M-12 | J2 | TYPE-C-31-M-12 | USB # C 2.0 RCPT TYPE-C-31-M-12 | China | HRO TYPE-C-31-M-12 | LCSC | C165948 | LCSC ALT | C167321 / C319148 | 1
ESP-WROVER-32 | ESP-32 based ESP-WROVER-32 | WiFi # MOD ESP-WROVER-32 | MOD1 | ESP-WROVER-32 | WiFi # MOD ESP-WROVER-32 | Espressif | ESP-WROVER-32 |  |  |  |  | 1
FPC_AFE03-S15FMA-1H | Bottom contact FPC 0.3mm pitch 15 contacts | FPC # 15 Bottom 0.3mm AFE03-S15FMA-1H | P8 | AFE03-S15FMA-1H | FPC # 15 Bottom 0.3mm AFE03-S15FMA-1H | LCSC | C262541 |  |  |  |  | 1
R0603_N |  | RES # 5K1 0603 | R1, R2, R4, R5, R6, R7, R11, R12, R13, R14, R15 | 5K1 | RES # 5K1 0603 | Farnell | 2845922 |  |  | Generic | 5K1 1% 0603 | 11
R0603_N |  | RES # 1K2 0603 | R3, R16, R18, R19, R20, R21, R23, R24, R25, R26 | 1K2 | RES # 1K2 0603 | Farnell | 2446592 |  |  | Generic | 1K2 1% 0603 | 10
R0603_N |  | RES # 100R 0603 | R8, R9, R10, R28 | 100R | RES # 100R 0603 | Farnell | 2446544 |  |  | Generic | 100R 1% 0603 | 4
R0603_N |  | RES # 100K 0603 | R17, R22 | 100K | RES # 100K 0603 |  |  |  |  | Generic | 100K 1% 0603 | 2
R0603_N |  | RES # 10K 0603 | R29, R30 | 10K | RES # 10K 0603 | Farnell | 2502397 |  |  | Generic | 10K 1% 0603 | 2
WE_430181038816 | 4.5x4.5mm tact SMD H3,8mm | SW # TACT small 4.5x4.5mm SMD WS-TASV | SW1, SW3 | 430181038816 | SW # TACT small 4.5x4.5mm SMD WS-TASV | Wurth | 430181038816 | Mouser | 710-430181038816 |  |  | 2
WE_450404015514 | WS-SLSU Mini slide switch 1P2T SMD | SW # 1P2T WS-SLSU mini slide 6,7 x 2,7 mm | SW2, SW4 | 450404015514 | SW # 1P2T WS-SLSU mini slide 6,7 x 2,7 mm | Digi-key | 732-13665-1-ND | LCSC | C431540 |  |  | 2
TACTSW | Default TH TACT | SW TACT | SW5, SW6, SW7, SW8 |  | SW TACT | LCSC | C393938 |  |  |  |  | 4
TACTSW_5W_K1-1506DN-01 | 5Way Tact switch | SW TACT 5W K1-1506DN-01 | SW9 | K1-1506DN-01 | SW TACT 5W K1-1506DN-01 | LCSC | C145911 |  |  |  |  | 1
TSSOP_8_65P | Dual N-Ch MOSFET Common Drain | FS8205A Dual N-Ch common Drain for DW01-P | T1 | FS8205A | FS8205A Dual N-Ch common Drain for DW01-P | AliExpress | FS8205A |  |  |  |  | 1
SOT23-3 | 0.2A N-Ch MOSFET Vgs 3.2 | BSS138 N-Ch MOSFET 0.2A 3.2Vgs 60Vds | T2, T3, T4 | BSS138 | BSS138 N-Ch MOSFET 0.2A 3.2Vgs 60Vds | Farnell | 2432717 |  |  |  |  | 3
SOT23-3 | 4.1A 20V P-Ch MOSFET Vgs -1.3V | SL2302 P-Ch MOSFET 4.1A 20Vds | T5 | SL2302 | SL2302 P-Ch MOSFET 4.1A 20Vds | LCSC | C251150 |  |  |  |  | 1
TP_0.8mm |  | TP # 0.8mm | TP11 | NO BOM | TP # 0.8mm |  |  |  |  |  |  | 1
STM_LGA12_2x2 | 3-Axis, ±2 g/±4 g/±8 g/±16 g Digital Accelerometer | ACCELERO # LIS2DH12 | U2 | LIS2DH12 | ACCELERO # LIS2DH12 | LCSC | C110926 |  |  |  |  | 1
QFN_24 | USB to UART 3.3-5V | CP2102N # QFN24 USB UART | U3 | CP2102N-A01-GQFN24 | CP2102N # QFN24 USB UART | Farnell | 2577278 | Digi-key | 336-3693-ND |  |  | 1
SOT23-5 | 3V3 LDO 700mA 50mV | LDO # 3V3 XC6210B33 | U4, U5 | XC6210B332MR | LDO # 3V3 XC6210B33 | Farnell | 1057803 |  |  |  |  | 2
SOIC_N_8_TH | Single Cell LiIon charger max 1A | CHG # TP4056 LiIon 1A | U6 | TP4056 | CHG # TP4056 LiIon 1A | Aliexpress | TP4056 |  |  |  |  | 1
AHT10 | AHT 10 Temperature and humidity sensor | TMP HUM # AHT10 | U7 | AHT10 | TMP HUM # AHT10 | LCSC | C368909 |  |  |  |  | 1
SOT23-6 | DW01-P single cell lithium protection | PWR # DW01-P Lithium protection | U8 | DW01-P | PWR # DW01-P Lithium protection | Aliexpress | DW01-P |  |  |  |  | 1
MAX_uSOP8 | 5W Class D mono amplifier inducter-less Differential input MSOP8 | AMP # AUDIO NS4150B | U9 | NS4150B | AMP # AUDIO NS4150B | LCSC | C189961 |  |  |  |  | 1
 |  |  |  |  |  |  |  |  |  |  |  | 98
Approved |  | Notes

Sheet: LCSC
Quantity | Manufacture Part Number | Manufacturer(optional) | Description(optional) | LCSC Part Number(optional) | Package(optional)
5 |  |  | IRM-3638N3F14 Infrared Receiver 38 kHz 45° 2.7-5.5V | C264262
5 |  |  | MBRA210LT3G Schottky Power Rectifier, 2A, 10V | C145190
5 |  |  | USB 2.0 C Reversible Receptacle Horizontal | C165948
5 |  |  | Bottom contact FPC 0.3mm pitch 15 contacts | C262541
55 |  |  | RES # 5K1 0603 | C112314
10 |  |  | 4.5x4.5mm tact SMD H3,8mm | C174049
10 |  |  | WS-SLSU Mini slide switch 1P2T SMD | C431540
20 |  |  | Default TH TACT | C393938
5 |  |  | 5Way Tact switch | C145911
5 |  |  | 4.1A 20V P-Ch MOSFET Vgs -1.3V | C251150
5 |  |  | 3-Axis, ±2 g/±4 g/±8 g/±16 g Digital Accelerometer | C110926
5 |  |  | USB to UART 3.3-5V | C47742
10 |  |  | 3V3 LDO 700mA 50mV | C47719
5 |  |  | Single Cell LiIon charger max 1A | C382139
5 |  |  | AHT 10 Temperature and humidity sensor | C368909

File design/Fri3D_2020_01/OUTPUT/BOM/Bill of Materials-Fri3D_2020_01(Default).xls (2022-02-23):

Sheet: BOM Report
Bill of Materials |  |  | Fri3D Badge 2020
Project: |  | Fri3D_2020_01.PrjPcb
Revision: |  | 01
Variant: |  | Default
Creation Date: | 25/03/2020 | 17:16
Print Date: | 2020-05-08 | 20:53:00
Footprint | Comment | LibRef | Designator | Value | Description | Supplier 1 | Supplier PNr 1 | Supplier 2 | Supplier PN 2 | Supplier 3 | Supplier PN 3 | QTY
BAT_18650_SPRING | 18650 Battery holder with spring | 18650 Battery holder spring CN | BAT1 | 18650_SPRING | 18650 Battery holder spring CN | TaoBao | 39761834568 |  |  |  |  | 1
CUI_CMT-1203-SMT | 12x12x3mm Piezo Buzzer Transducer 81dB | BUZ # CUI CMT-1203-SMT | BUZ1 | CMT-1203-SMT | BUZ # CUI CMT-1203-SMT | Digi-key | 102-2197-1-ND | LCSC | C391037 |  |  | 1
C0603_N |  | CAP # 100nF 16V 0603 | C1, C2, C3, C4, C7, C8, C9, C11, C13, C22 | 100nF 16V | CAP # 100nF 16V 0603 |  |  |  |  | Generic | 100nF 16V 0603 X7R | 10
C0603_N |  | CAP # 1uF 16V 0603 | C5, C18, C19, C20, C21 | 1uF 16V | CAP # 1uF 16V 0603 | Farnell | 2320814 |  |  | Generic | 1uF 16V 0603 X7R | 5
C0805_N |  | CAP # 10uF 10V 0805 | C10, C12, C14, C15, C16, C17 | 10uF 10V | CAP # 10uF 10V 0805 | Farnell | 2320859 |  |  | Generic | 10uF 10V 0805 X7R | 6
LED_5050_WS2812B_BLACK | WS2812 based digital RGB LED 5050 Black package | LED # RGB WS2812B-5050 BL | D1, D2, D3, D4, D5 | WS218B 5050 BL | LED # RGB WS2812B-5050 BL | LCSC | C114586 |  |  |  |  | 5
VIS_TSOP381x_BENT | IRM-3638N3F14 Infrared Receiver 38 kHz 45° 2.7-5.5V | PHO IR Rx RA | D6 | IRM-3638N3F14 | PHO IR Rx RA | LCSC | C264262 |  |  |  |  | 1
LED_0805_RD | Default 0805 Red LED | LED # Red 0805 | D7, D8, D11 |  | LED # Red 0805 | Farnell | 2099236 |  |  |  |  | 3
LED_0805_GR | Default 0805 Green LED | LED # Green 0805 | D9, D10, D12 |  | LED # Green 0805 | Farnell | 2099239 |  |  |  |  | 3
SMA_AC | MBRA210LT3G Schottky Power Rectifier, 2A, 10V | Schottky # MBRA210LT3G | D13 | MBRA210LT3G | Schottky # MBRA210LT3G | LCSC | C145190 |  |  |  |  | 1
HRO_TYPE-C-31-M-12 | USB 2.0 C Reversible Receptacle Horizontal | USB # C 2.0 RCPT TYPE-C-31-M-12 | J2 | TYPE-C-31-M-12 | USB # C 2.0 RCPT TYPE-C-31-M-12 | China | HRO TYPE-C-31-M-12 | LCSC | C165948 | LCSC ALT | C167321 / C319148 | 1
ESP-WROVER-32 | ESP-32 based ESP-WROVER-32 | WiFi # MOD ESP-WROVER-32 | MOD1 | ESP-WROVER-32 | WiFi # MOD ESP-WROVER-32 | Espressif | ESP-WROVER-32 |  |  |  |  | 1
FPC_AFE03-S15FMA-1H | Bottom contact FPC 0.3mm pitch 15 contacts | FPC # 15 Bottom 0.3mm AFE03-S15FMA-1H | P1 | AFE03-S15FMA-1H | FPC # 15 Bottom 0.3mm AFE03-S15FMA-1H | LCSC | C262541 |  |  |  |  | 1
R0603_N |  | RES # 100R 0603 | R1, R4, R6, R29 | 100R | RES # 100R 0603 | Farnell | 2446544 |  |  | Generic | 100R 1% 0603 | 4
R0603_N |  | RES # 5K1 0603 | R2, R5, R7, R8, R9, R10, R20, R21, R32, R35, R37, R38 | 5K1 | RES # 5K1 0603 | Farnell | 2845922 | LCSC | C112314 | Generic | 5K1 1% 0603 | 12
R0603_N |  | RES # 1K2 0603 | R11, R13, R14, R15, R16, R22, R23, R24, R30, R36 | 1K2 | RES # 1K2 0603 | Farnell | 2446592 |  |  | Generic | 1K2 1% 0603 | 10
R0603_N |  | RES # 100K 0603 | R12, R17, R25, R26 | 100K | RES # 100K 0603 |  |  |  |  | Generic | 100K 1% 0603 | 4
R0402 |  | NTC # 10K 0402 | R27 | 10K | NTC # 10K 0402 | LCSC | C209959 | LCSC | C98099 |  |  | 1
R0603_N |  | RES # 0R 0603 | R33 | 0R | RES # 0R 0603 | Farnell | 2447743 |  |  | Generic | 0R 1% 0603 | 1
WE_450404015514 | WS-SLSU Mini slide switch 1P2T SMD | SW # 1P2T WS-SLSU mini slide 6,7 x 2,7 mm | SW1, SW4 | 450404015514 | SW # 1P2T WS-SLSU mini slide 6,7 x 2,7 mm | Digi-key | 732-13665-1-ND | LCSC | C431540 |  |  | 2
SOT23-3 | 0.2A N-Ch MOSFET Vgs 3.2 | BSS138 N-Ch MOSFET 0.2A 3.2Vgs 60Vds | T1, T2, T3 | BSS138 | BSS138 N-Ch MOSFET 0.2A 3.2Vgs 60Vds | Farnell | 2432717 | LCSC | C426569 |  |  | 3
TSSOP_8_65P | Dual N-Ch MOSFET Common Drain | FS8205A Dual N-Ch common Drain for DW01-P | T5 | FS8205A | FS8205A Dual N-Ch common Drain for DW01-P | LCSC | C16052 |  |  |  |  | 1
SOT23-3 | -2.3A -20V P-Ch MOSFET Vgs -1V | SL2301 P-Ch MOSFET -2.3A -20Vds | T6, T7 | SL2301 | SL2301 P-Ch MOSFET -2.3A -20Vds | LCSC | C181086 |  |  |  |  | 2
TP_0.8mm |  | TP # 0.8mm | TP1 | NO BOM | TP # 0.8mm |  |  |  |  |  |  | 1
STM_LGA12_2x2 | 3-Axis, ±2 g/±4 g/±8 g/±16 g Digital Accelerometer | ACCELERO # LIS2DH12 | U1 | LIS2DH12 | ACCELERO # LIS2DH12 | LCSC | C110926 |  |  |  |  | 1
AHT10 | AHT 10 Temperature and humidity sensor | TMP HUM # AHT10 | U3 | AHT10 | TMP HUM # AHT10 | LCSC | C368909 |  |  |  |  | 1
QFN_24 | USB to UART 3.3-5V | CP2102N # QFN24 USB UART | U4 | CP2102N-A01-GQFN24 | CP2102N # QFN24 USB UART | Farnell | 2577278 | Digi-key | 336-3693-ND |  |  | 1
SOIC_N_8_TH | Single Cell LiIon charger max 1A | CHG # TP4056 LiIon 1A | U5 | TP4056 | CHG # TP4056 LiIon 1A | LCSC | C382139 |  |  |  |  | 1
SOT23-5 | 3V3 LDO 700mA 50mV | LDO # 3V3 XC6210B33 | U6, U7 | XC6210B332MR | LDO # 3V3 XC6210B33 | Farnell | 1057803 | LCSC | C47719 |  |  | 2
SOT23-6 | DW01-P single cell lithium protection | PWR # DW01-P Lithium protection | U8 | DW01-P | PWR # DW01-P Lithium protection | LCSC | C181096 |  |  |  |  | 1
 |  |  |  |  |  |  |  |  |  |  |  | 87
Approved |  | Notes

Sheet: Print
Footprint | Comment | LibRef | Designator | Value | Description | QTY | 5 | PLACE
BAT_18650_SPRING | 18650 Battery holder with spring | 18650 Battery holder spring CN | BAT1 | 18650_SPRING | 18650 Battery holder spring CN | 1 | 5
CUI_CMT-1203-SMT | 12x12x3mm Piezo Buzzer Transducer 81dB | BUZ # CUI CMT-1203-SMT | BUZ1 | CMT-1203-SMT | BUZ # CUI CMT-1203-SMT | 1 | 5
C0603_N |  | CAP # 100nF 16V 0603 | C1, C2, C3, C4, C7, C8, C9, C11, C13, C22 | 100nF 16V | CAP # 100nF 16V 0603 | 10 | 50
C0603_N |  | CAP # 1uF 16V 0603 | C5, C18, C19, C20, C21 | 1uF 16V | CAP # 1uF 16V 0603 | 5 | 25
C0805_N |  | CAP # 10uF 10V 0805 | C10, C12, C14, C15, C16, C17 | 10uF 10V | CAP # 10uF 10V 0805 | 6 | 30
LED_5050_WS2812B_BLACK | WS2812 based digital RGB LED 5050 Black package | LED # RGB WS2812B-5050 BL | D1, D2, D3, D4, D5 | WS218B 5050 BL | LED # RGB WS2812B-5050 BL | 5 | 25
VIS_TSOP381x_BENT | IRM-3638N3F14 Infrared Receiver 38 kHz 45° 2.7-5.5V | PHO IR Rx RA | D6 | IRM-3638N3F14 | PHO IR Rx RA | 1 | 5
LED_0805_RD | Default 0805 Red LED | LED # Red 0805 | D7, D8, D11 |  | LED # Red 0805 | 3 | 15
LED_0805_GR | Default 0805 Green LED | LED # Green 0805 | D9, D10, D12 |  | LED # Green 0805 | 3 | 15
SMA_AC | MBRA210LT3G Schottky Power Rectifier, 2A, 10V | Schottky # MBRA210LT3G | D13 | MBRA210LT3G | Schottky # MBRA210LT3G | 1 | 5
HRO_TYPE-C-31-M-12 | USB 2.0 C Reversible Receptacle Horizontal | USB # C 2.0 RCPT TYPE-C-31-M-12 | J2 | TYPE-C-31-M-12 | USB # C 2.0 RCPT TYPE-C-31-M-12 | 1 | 5
ESP-WROVER-32 | ESP-32 based ESP-WROVER-32 | WiFi # MOD ESP-WROVER-32 | MOD1 | ESP-WROVER-32 | WiFi # MOD ESP-WROVER-32 | 1 | 5
FPC_AFE03-S15FMA-1H | Bottom contact FPC 0.3mm pitch 15 contacts | FPC # 15 Bottom 0.3mm AFE03-S15FMA-1H | P1 | AFE03-S15FMA-1H | FPC # 15 Bottom 0.3mm AFE03-S15FMA-1H | 1 | 5
R0603_N |  | RES # 100R 0603 | R1, R4, R6, R29 | 100R | RES # 100R 0603 | 4 | 20
R0603_N |  | RES # 5K1 0603 | R2, R5, R7, R8, R9, R10, R20, R21, R32, R35, R37, R38 | 5K1 | RES # 5K1 0603 | 12 | 60
R0603_N |  | RES # 1K2 0603 | R11, R13, R14, R15, R16, R22, R23, R24, R30, R36 | 1K2 | RES # 1K2 0603 | 10 | 50
R0603_N |  | RES # 100K 0603 | R12, R17, R25, R26 | 100K | RES # 100K 0603 | 4 | 20
R0402 |  | NTC # 10K 0402 | R27 | 10K | NTC # 10K 0402 | 1 | 5
R0603_N |  | RES # 0R 0603 | R33 | 0R | RES # 0R 0603 | 1 | 5
WE_450404015514 | WS-SLSU Mini slide switch 1P2T SMD | SW # 1P2T WS-SLSU mini slide 6,7 x 2,7 mm | SW1, SW4 | 450404015514 | SW # 1P2T WS-SLSU mini slide 6,7 x 2,7 mm | 2 | 10
SOT23-3 | 0.2A N-Ch MOSFET Vgs 3.2 | BSS138 N-Ch MOSFET 0.2A 3.2Vgs 60Vds | T1, T2, T3 | BSS138 | BSS138 N-Ch MOSFET 0.2A 3.2Vgs 60Vds | 3 | 15
TSSOP_8_65P | Dual N-Ch MOSFET Common Drain | FS8205A Dual N-Ch common Drain for DW01-P | T5 | FS8205A | FS8205A Dual N-Ch common Drain for DW01-P | 1 | 5
SOT23-3 | -2.3A -20V P-Ch MOSFET Vgs -1V | SL2301 P-Ch MOSFET -2.3A -20Vds | T6, T7 | SL2301 | SL2301 P-Ch MOSFET -2.3A -20Vds | 2 | 10
TP_0.8mm |  | TP # 0.8mm | TP1 | NO BOM | TP # 0.8mm | 1 | 5
STM_LGA12_2x2 | 3-Axis, ±2 g/±4 g/±8 g/±16 g Digital Accelerometer | ACCELERO # LIS2DH12 | U1 | LIS2DH12 | ACCELERO # LIS2DH12 | 1 | 5
AHT10 | AHT 10 Temperature and humidity sensor | TMP HUM # AHT10 | U3 | AHT10 | TMP HUM # AHT10 | 1 | 5
QFN_24 | USB to UART 3.3-5V | CP2102N # QFN24 USB UART | U4 | CP2102N-A01-GQFN24 | CP2102N # QFN24 USB UART | 1 | 5
SOIC_N_8_TH | Single Cell LiIon charger max 1A | CHG # TP4056 LiIon 1A | U5 | TP4056 | CHG # TP4056 LiIon 1A | 1 | 5
SOT23-5 | 3V3 LDO 700mA 50mV | LDO # 3V3 XC6210B33 | U6, U7 | XC6210B332MR | LDO # 3V3 XC6210B33 | 2 | 10
SOT23-6 | DW01-P single cell lithium protection | PWR # DW01-P Lithium protection | U8 | DW01-P | PWR # DW01-P Lithium protection | 1 | 5
 |  |  |  |  |  | 87

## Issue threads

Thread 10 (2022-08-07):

Write a basic HOWTO

calmera, 2022-08-07:
Should contain the following:
- How to connect to the badge from win/lin/mac
- How to make modifications to the different output components (display, buzzer, pixels)
- How to read information from the badge sensors
- Where to get help

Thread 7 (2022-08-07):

Add Accelero to the library

calmera, 2022-08-07:
Currently the accelerometer is not supported, a lib needs to be created and wired into the Fri3d class

KoenBuys, 2022-08-08:
https://github.com/tuupola/micropython-lis2hh12, but it seems I'm too late ...

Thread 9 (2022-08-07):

Allow for easy modifications to the default app

calmera, 2022-08-07:
Thinking about changing eye color etc.

I was playing with using BLE to change these, but that didn't really seem to do the trick. Unable to detect the device

KoenBuys, 2022-08-08:
where is the default app located? @calmera

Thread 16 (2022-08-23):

Optional addons

nathansamson, 2022-08-23:
During fri3d there was a talk with some extra details about HW
Will the slides be made available?

I am mostly interested in adding CO2 and temperature sensor (if I remember correctly that was mentioned)

Also I dont think it was mentioned in the slides, but some basic instructions on how to add them would be nice (eg for CO2 sensor I see that IO26 / IO15 should be used but I can't immediately find it on the physical layout)

Brubacker, 2022-08-25:
Information regarding those parts and the presentation have been added to the repository.

nathansamson, 2022-08-30:
Thanks for adding those

I am still missing the connected ports for the "Temperature and Humidity sensor" (which also isn't mentioned on the block diagram)

The docs for the CO2 sensor can also receive a little improvement (I would create a MR for this but I am not sure if I am correct)

"With the help of P5 and P8 SMD headers ... Alternatively, there is also room for the [Molex 53261-0771](https://www.molex.com/molex/products/part-detail/pcb_headers/0532610771) SMD connector"

Its not mentioned but I assume this alternative method is on the P9 connector (its the only one that seems to fit).
Is the P9 also connected to the same ports (IO26/IO15) or is it connected to other ports as well?

Brubacker, 2022-08-31:
Which ports are you referring to? The Würth temperature and humidity sensor is connector to I²C (IO21 for SDA, IO22 for SCL) The address is included in the schematic (0x5F)
If you prefer not to solder them, I would suggest looking at [Stemma QT ](https://www.adafruit.com/category/620) or [QWIIC](https://www.sparkfun.com/qwiic) sensors, those are also connected to the same I²C bus.

I have updated the the readme to include the reference to P9.
Indeed, both connectors connect to the same pins (so you can't add two CO2 sensors)

nathansamson, 2022-08-31:
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

A) For me it wasn't clear the temp sensor correlated to the Stemma QT connector :) (Probably might need some clarification as well)
I already ordered the sensors to solder on so Ill have to visit a makerspace where I can try to solder it on :)

B) Now I realize its on the i2c bus I understand that I only need the address which would be part of the sensor spec and not specific to this board config. I also assume that most users actually  generally don't need to know this address since its coded in the arduino library (fun fact: I don't intend to use the arduino library so I probably would need to know this anyway, but I would then have found it myself).

Thanks for everything :)

Closed 2022-08-25.

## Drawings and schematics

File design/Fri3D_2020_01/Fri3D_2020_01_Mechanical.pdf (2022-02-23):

## Fri3D Badge 2020 Mechanical drawings

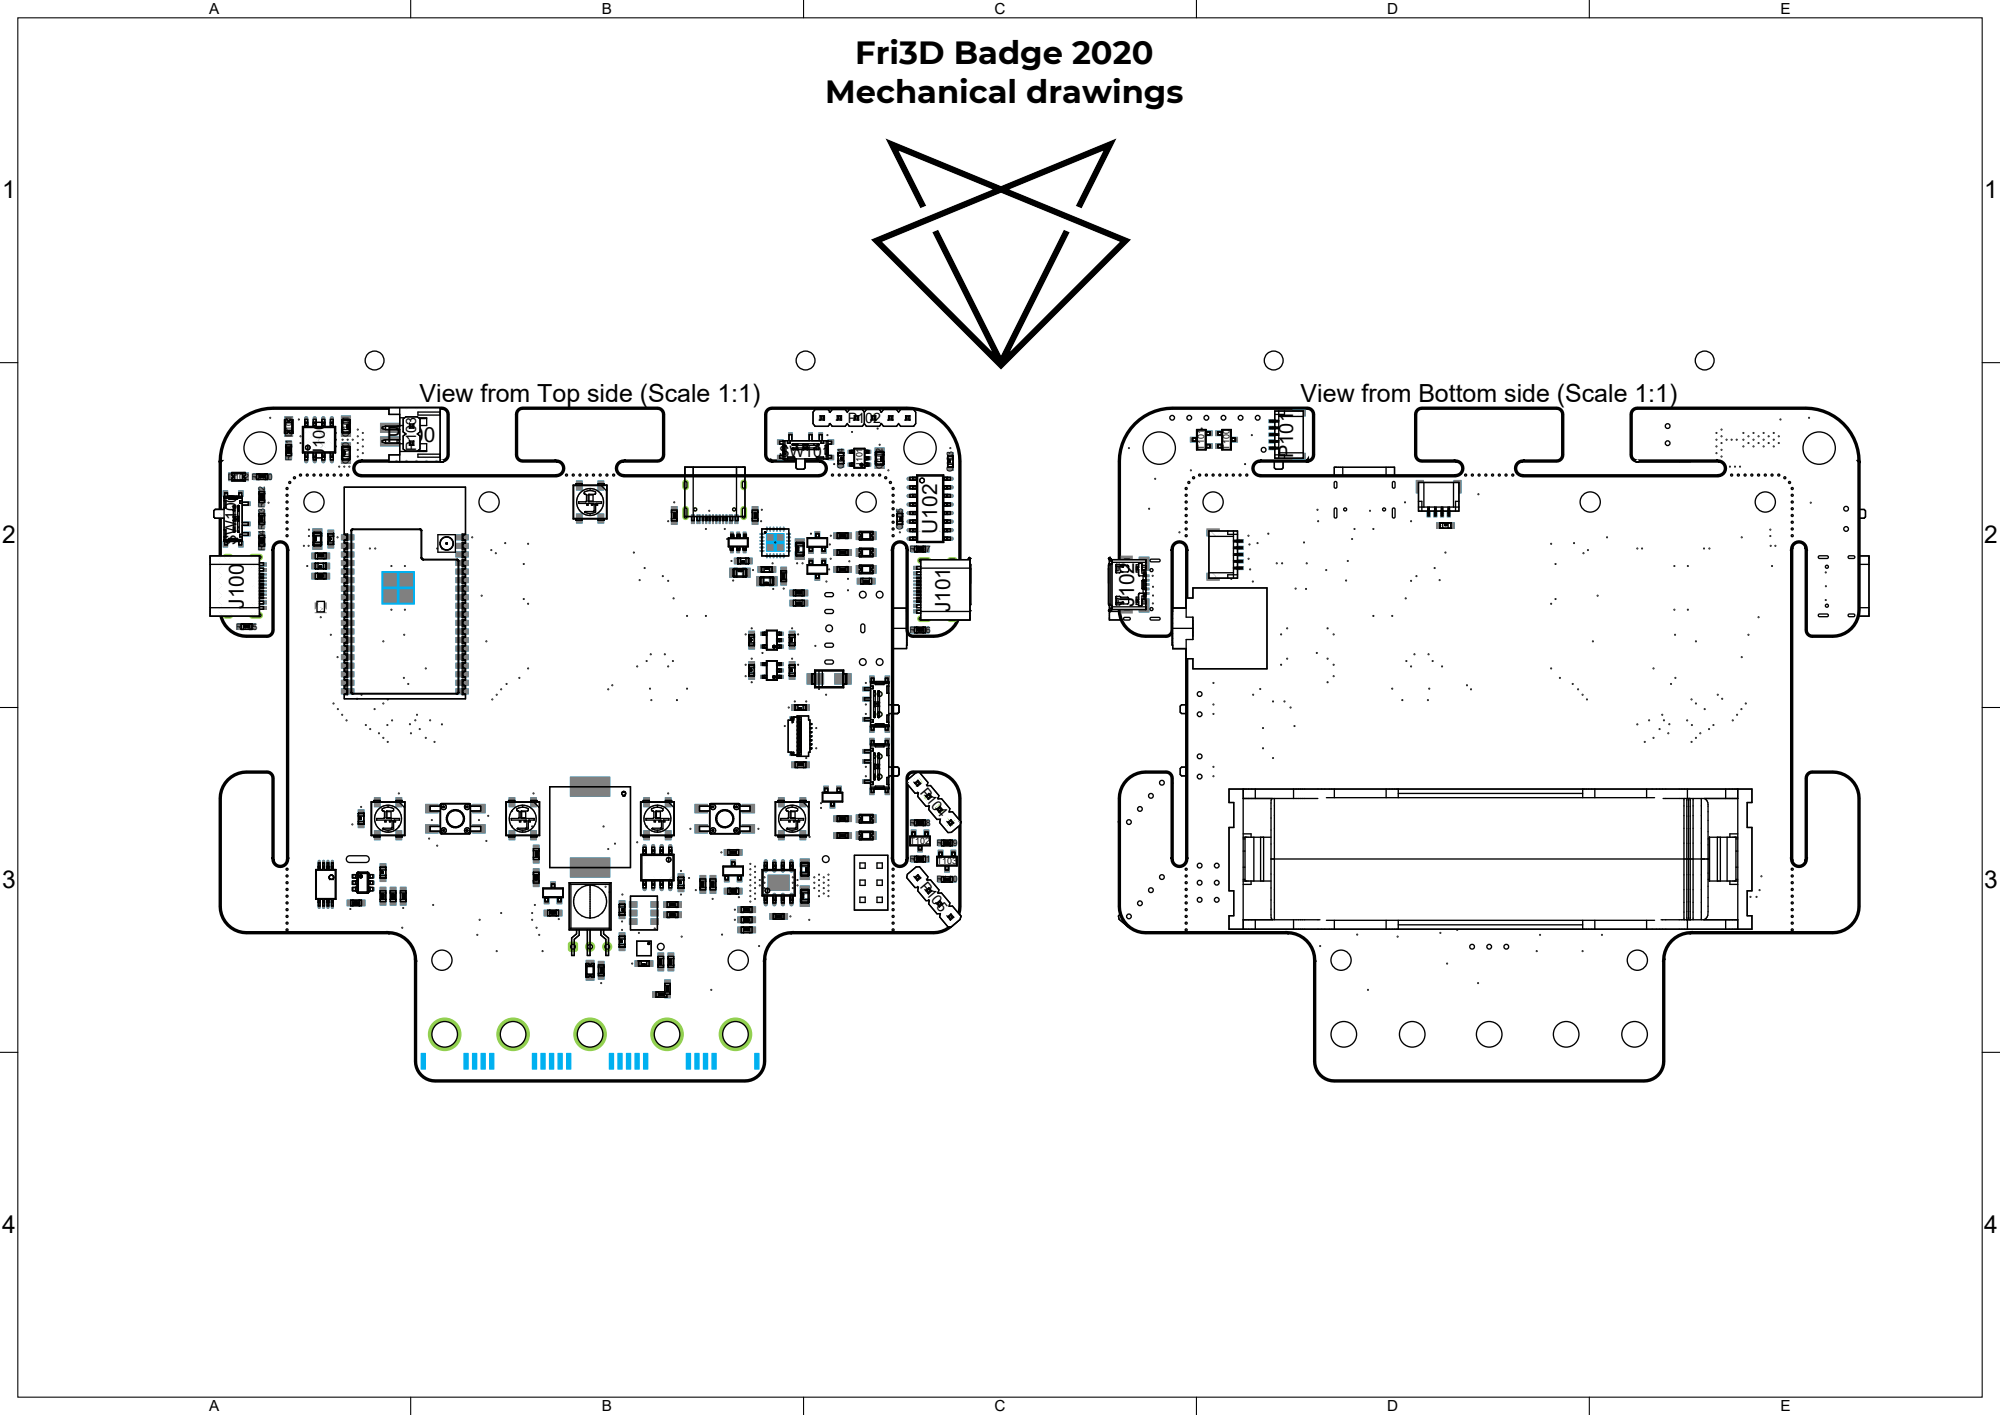
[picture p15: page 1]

View from Bottom side (Scale 1:1)

## Fri3D Badge 2020 Silkscreen

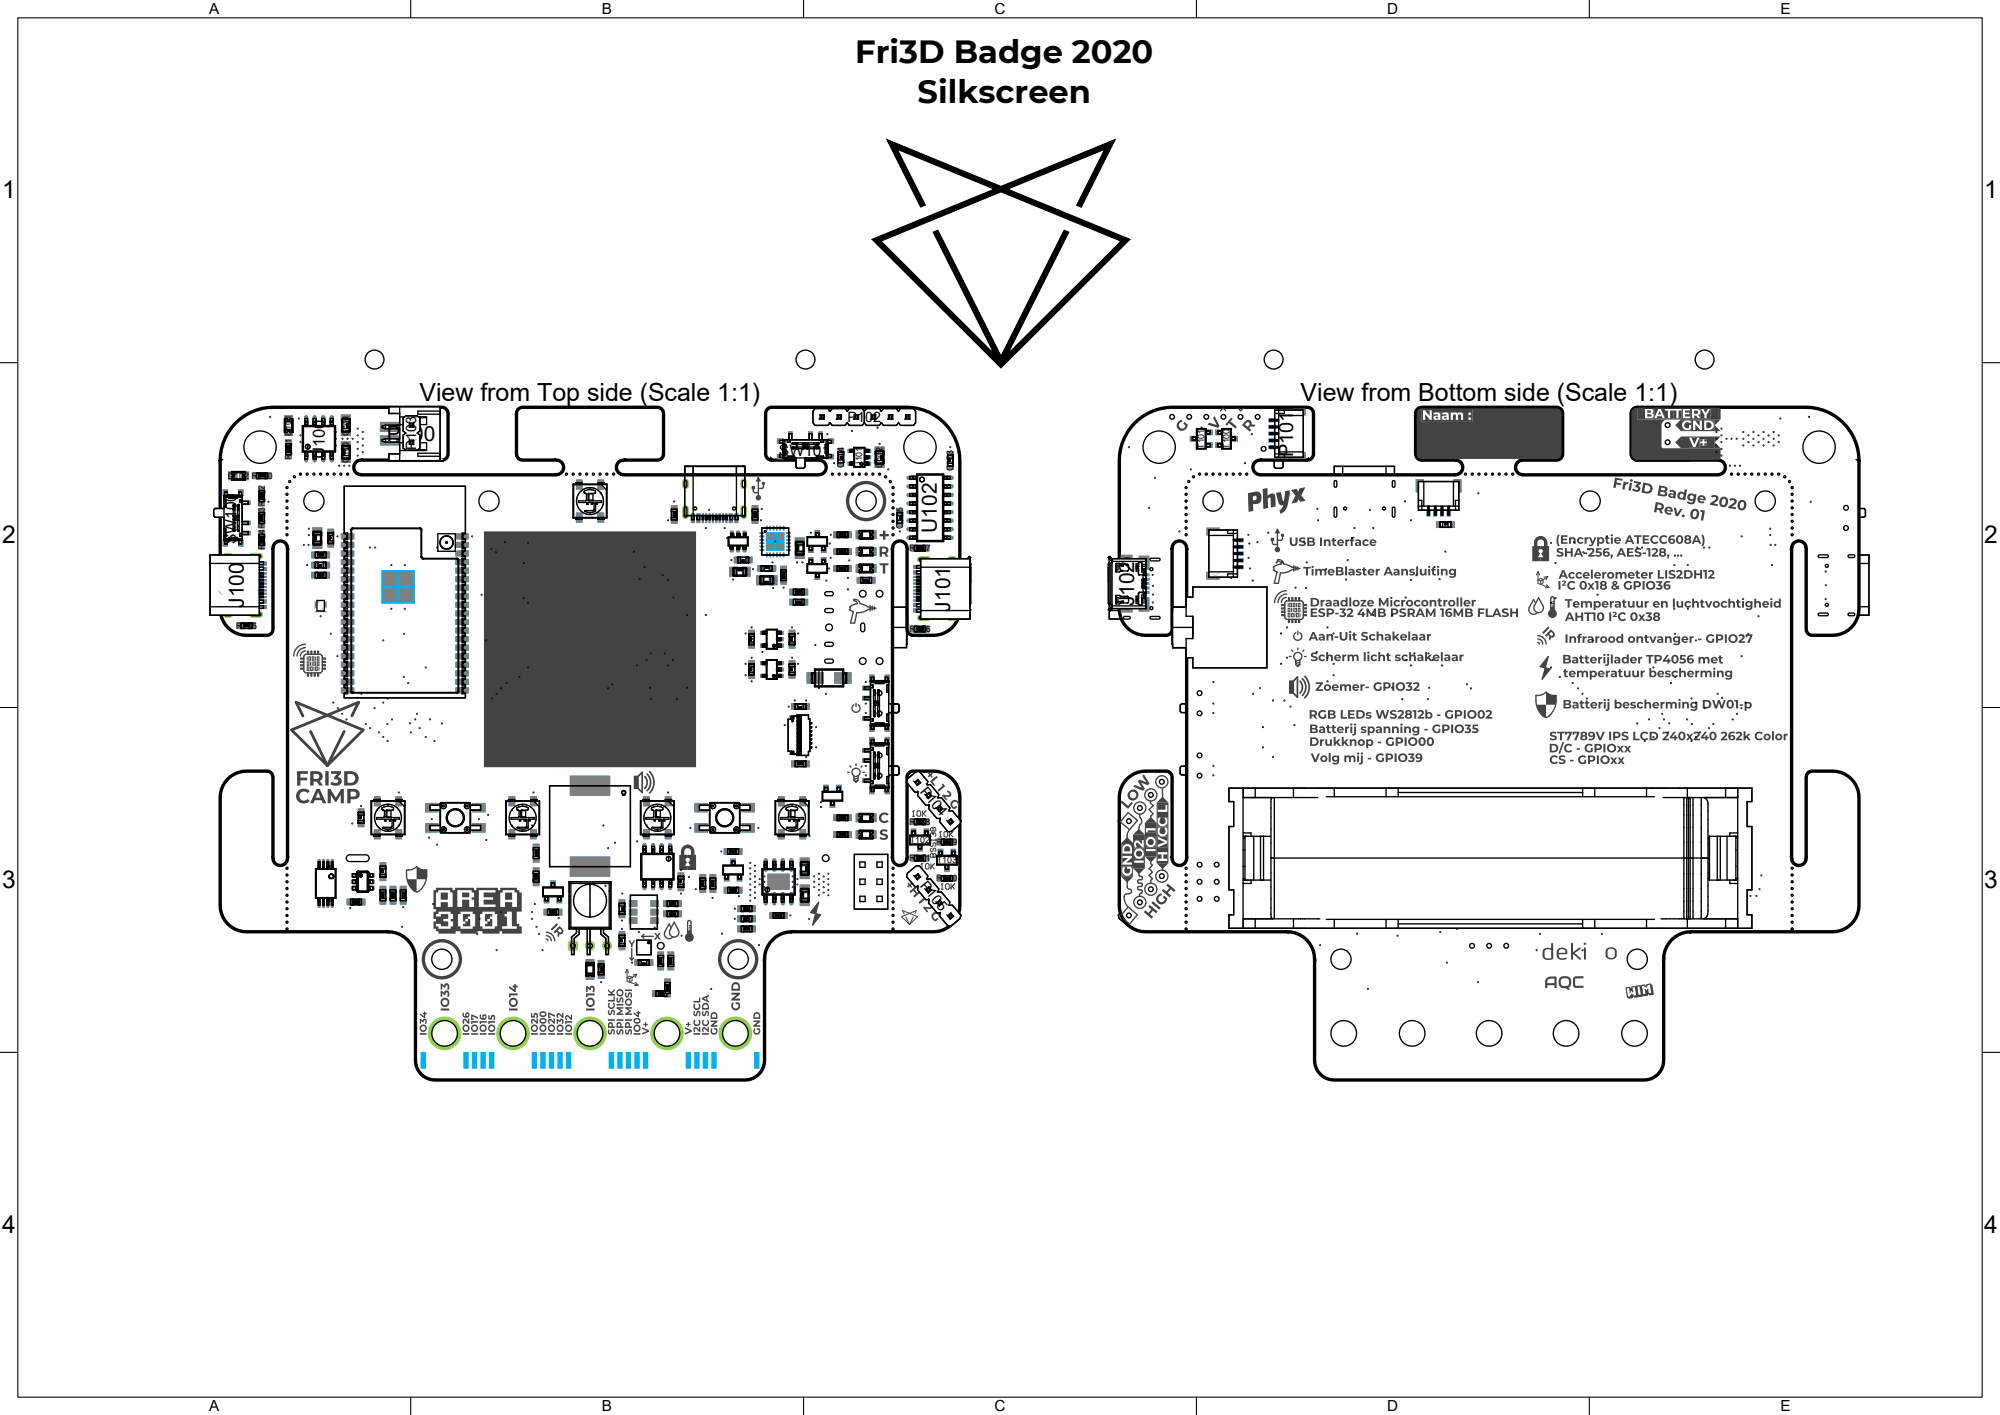
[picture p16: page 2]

View from Bottom side (Scale 1:1)

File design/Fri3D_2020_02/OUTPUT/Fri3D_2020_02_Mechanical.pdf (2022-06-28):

## Fri3D Badge 2020 Mechanical drawings

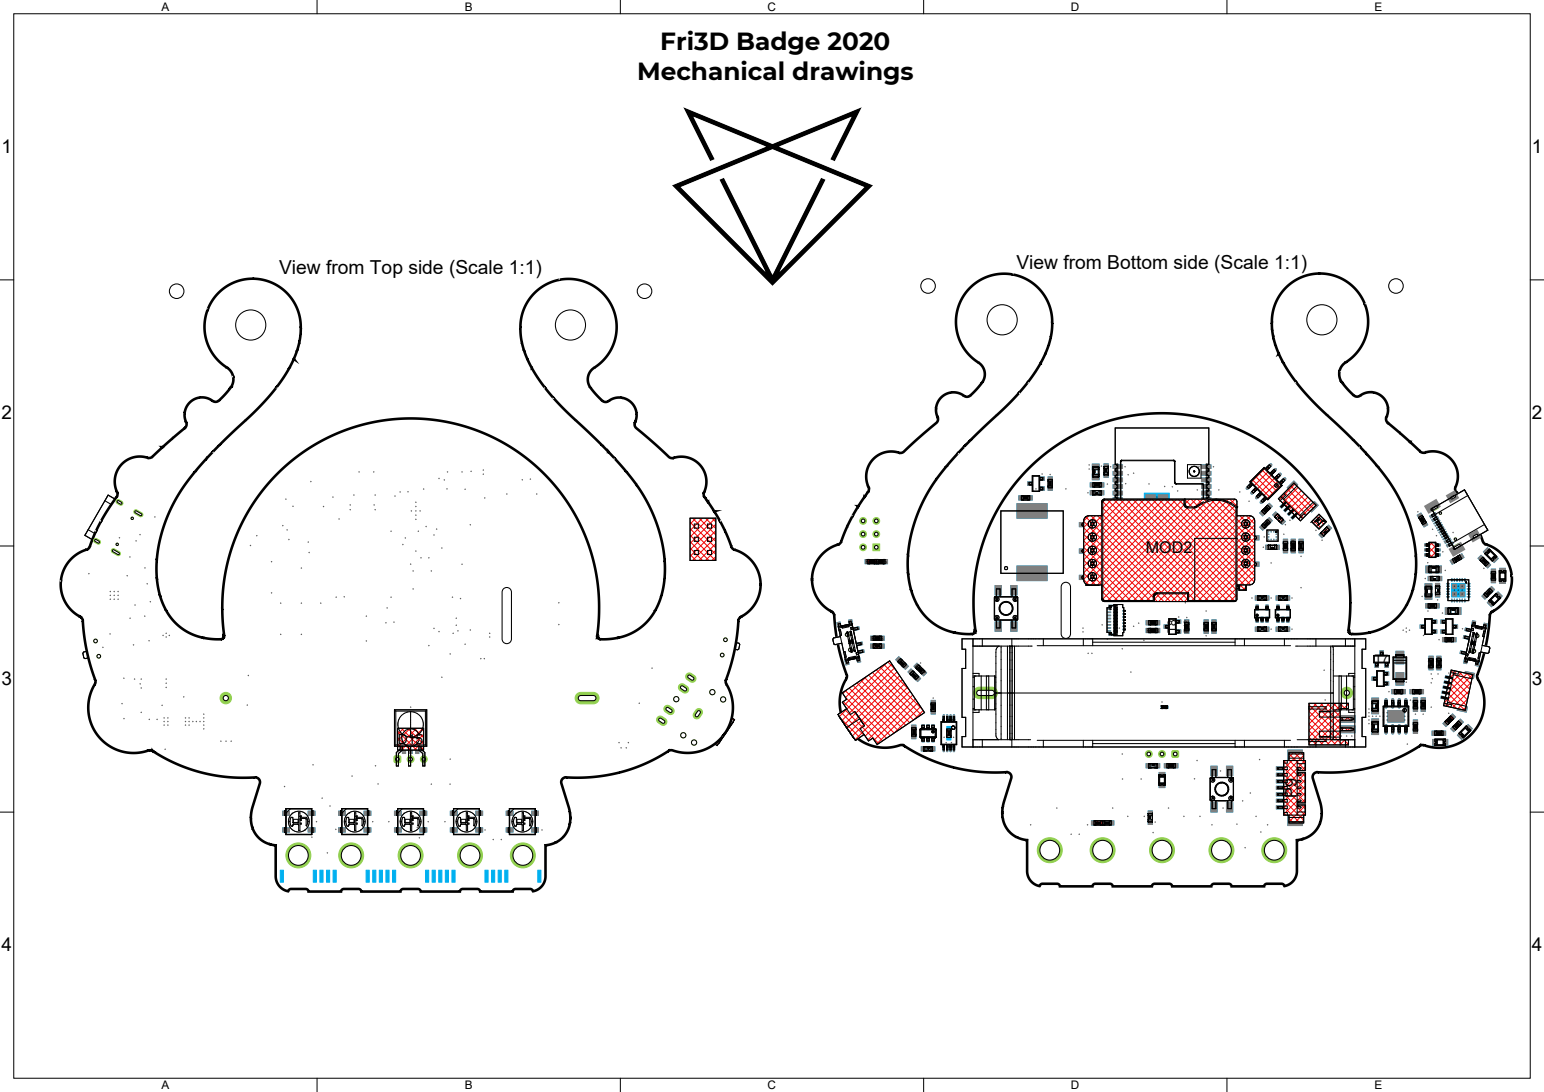
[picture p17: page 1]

View from Top side (Scale 1:1)

View from Bottom side (Scale 1:1)

## Fri3D Badge 2020 Silkscreen

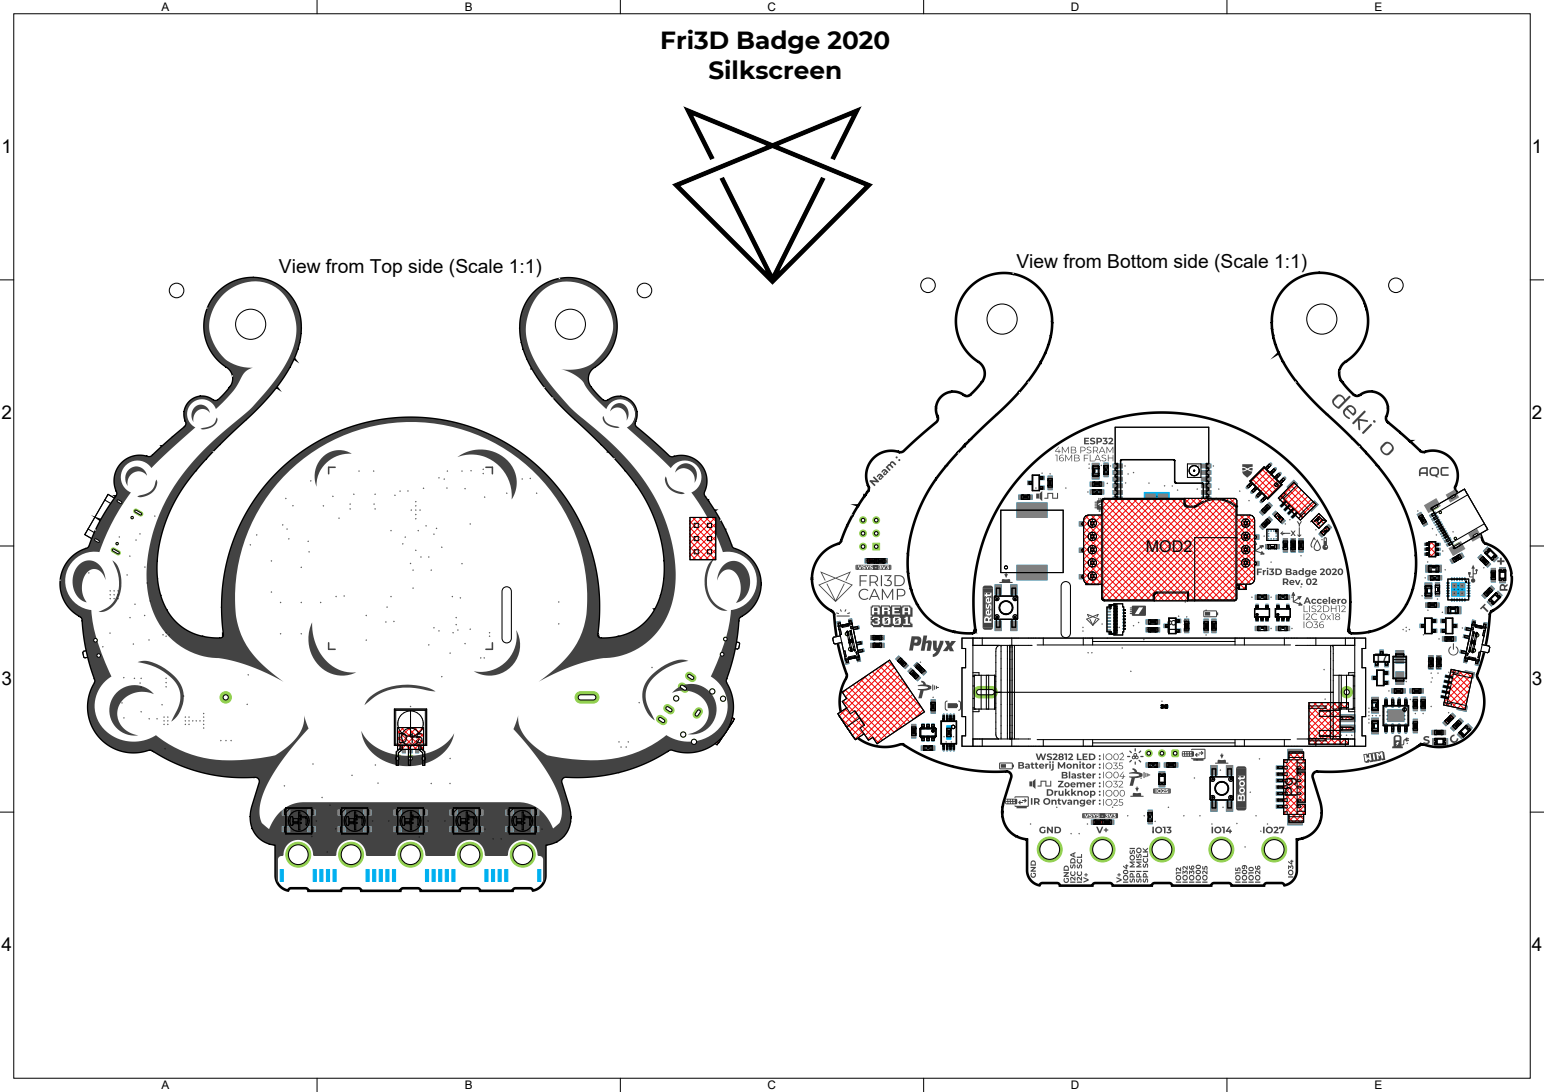
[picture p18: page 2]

View from Top side (Scale 1:1)

View from Bottom side (Scale 1:1)

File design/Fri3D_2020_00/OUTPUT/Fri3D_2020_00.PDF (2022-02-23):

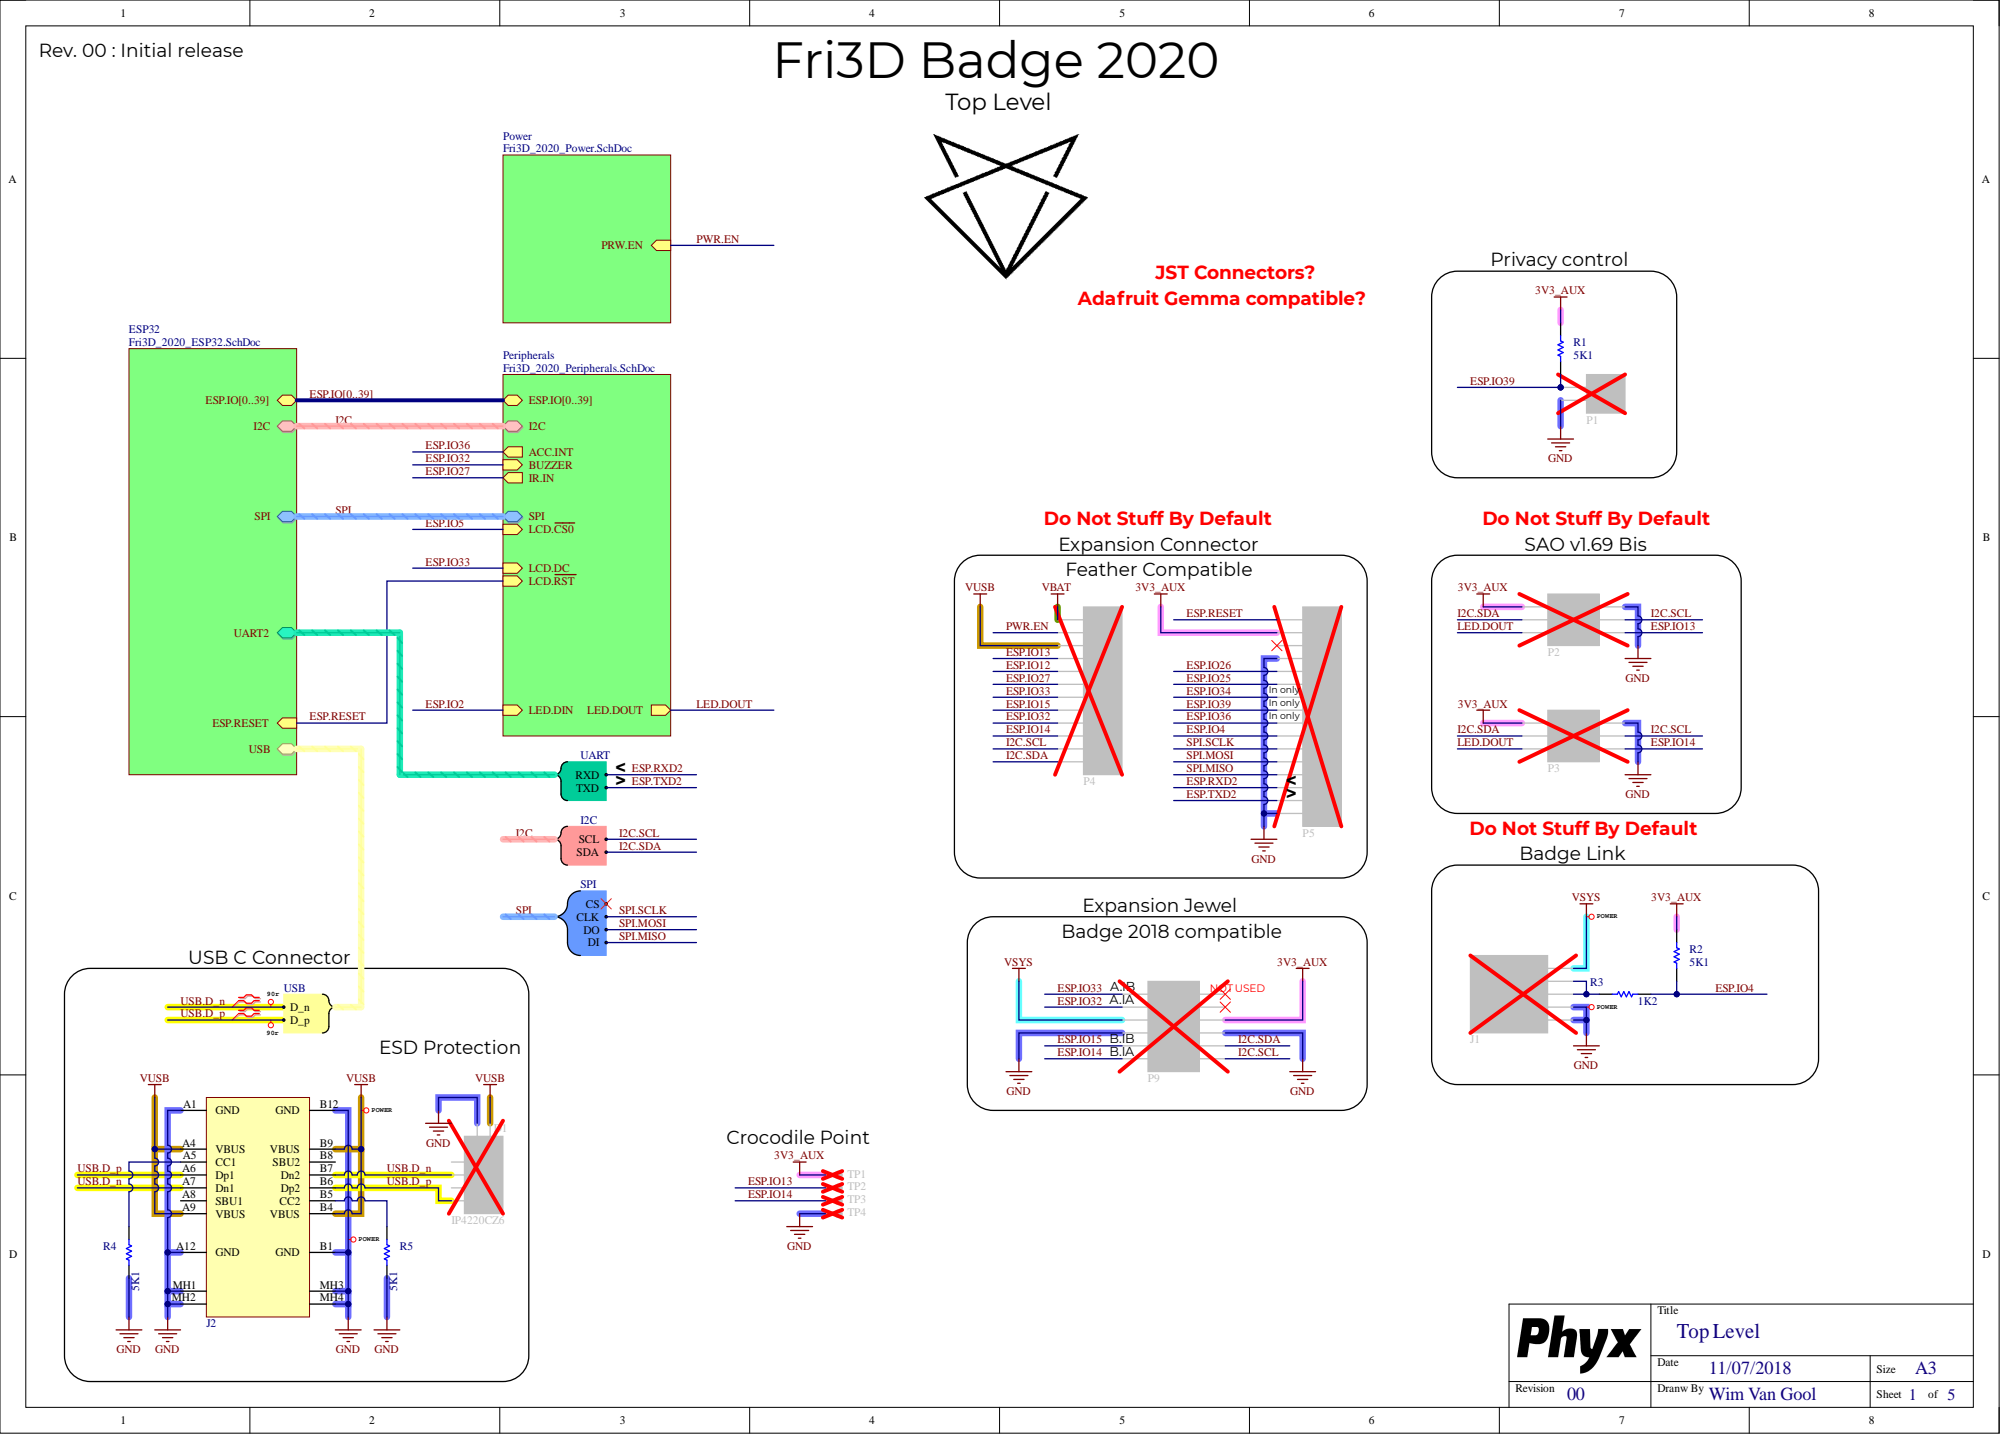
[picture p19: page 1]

Do Not Stuff By Default
Expansion Connector
Feather Compatible

SAO v1.69 Bis

Badge Link

MH1 | MH3
MH2 | MH4

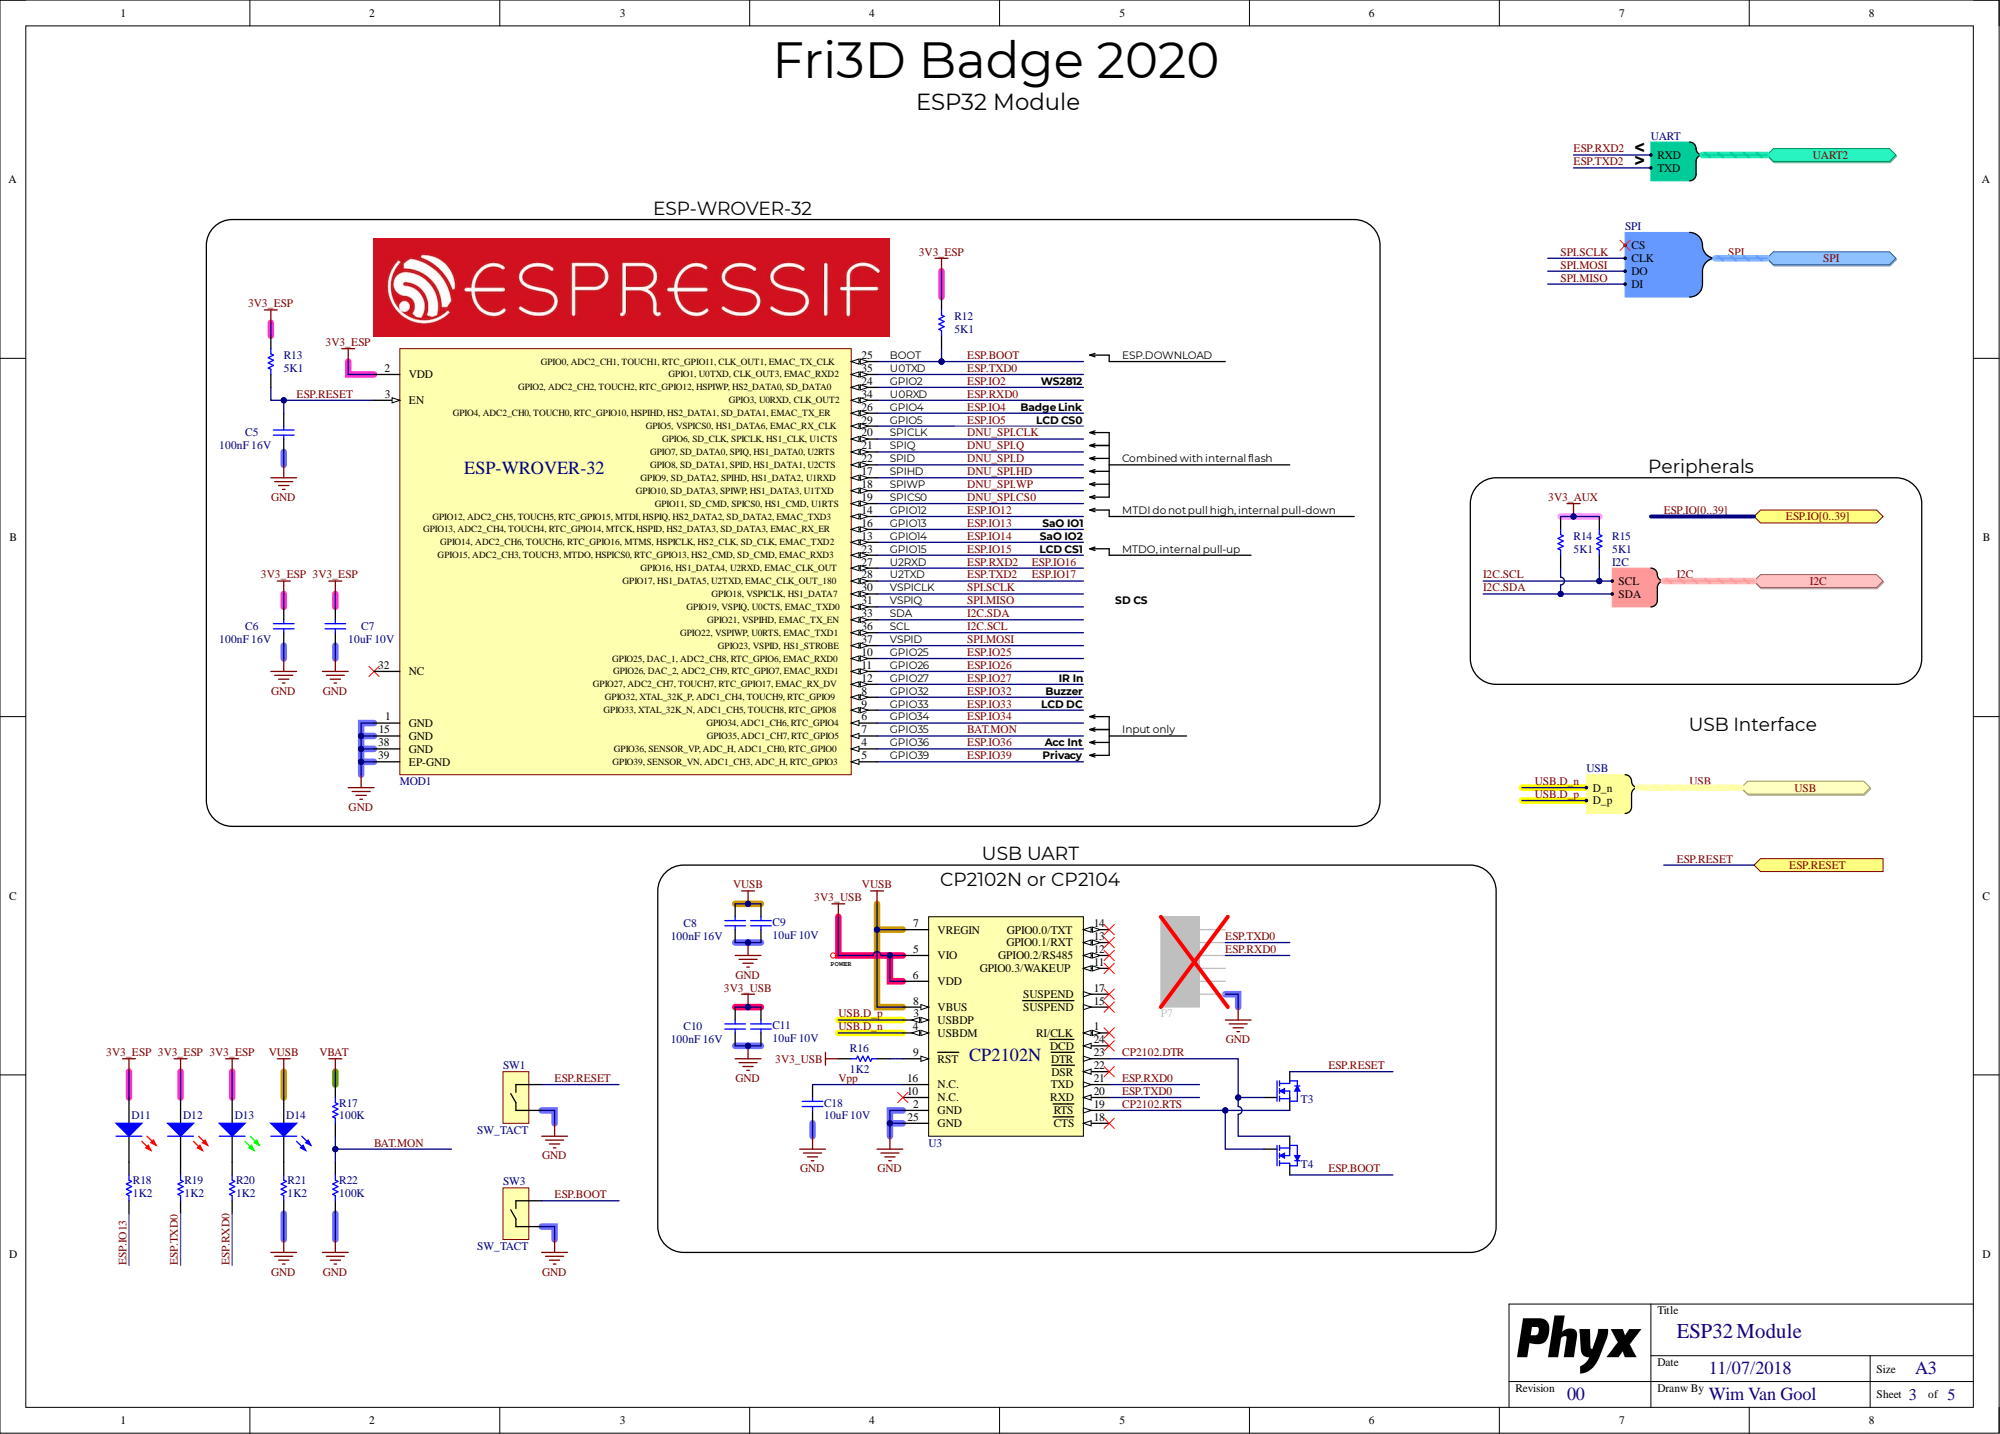
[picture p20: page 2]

Combined with internal flash

MTDI donot pull high, internal pull-down

ESP.IO[0..39]

MTDO, internal pull-up

GND 38 | GPIO36 ESP.IO36 Acc Int
EP-GND 39

N.C. 16 | | ESP.RXD0
N.C. 10 | | ESP.TXD0
GND 2 | | CP2102.RTS
GND 25

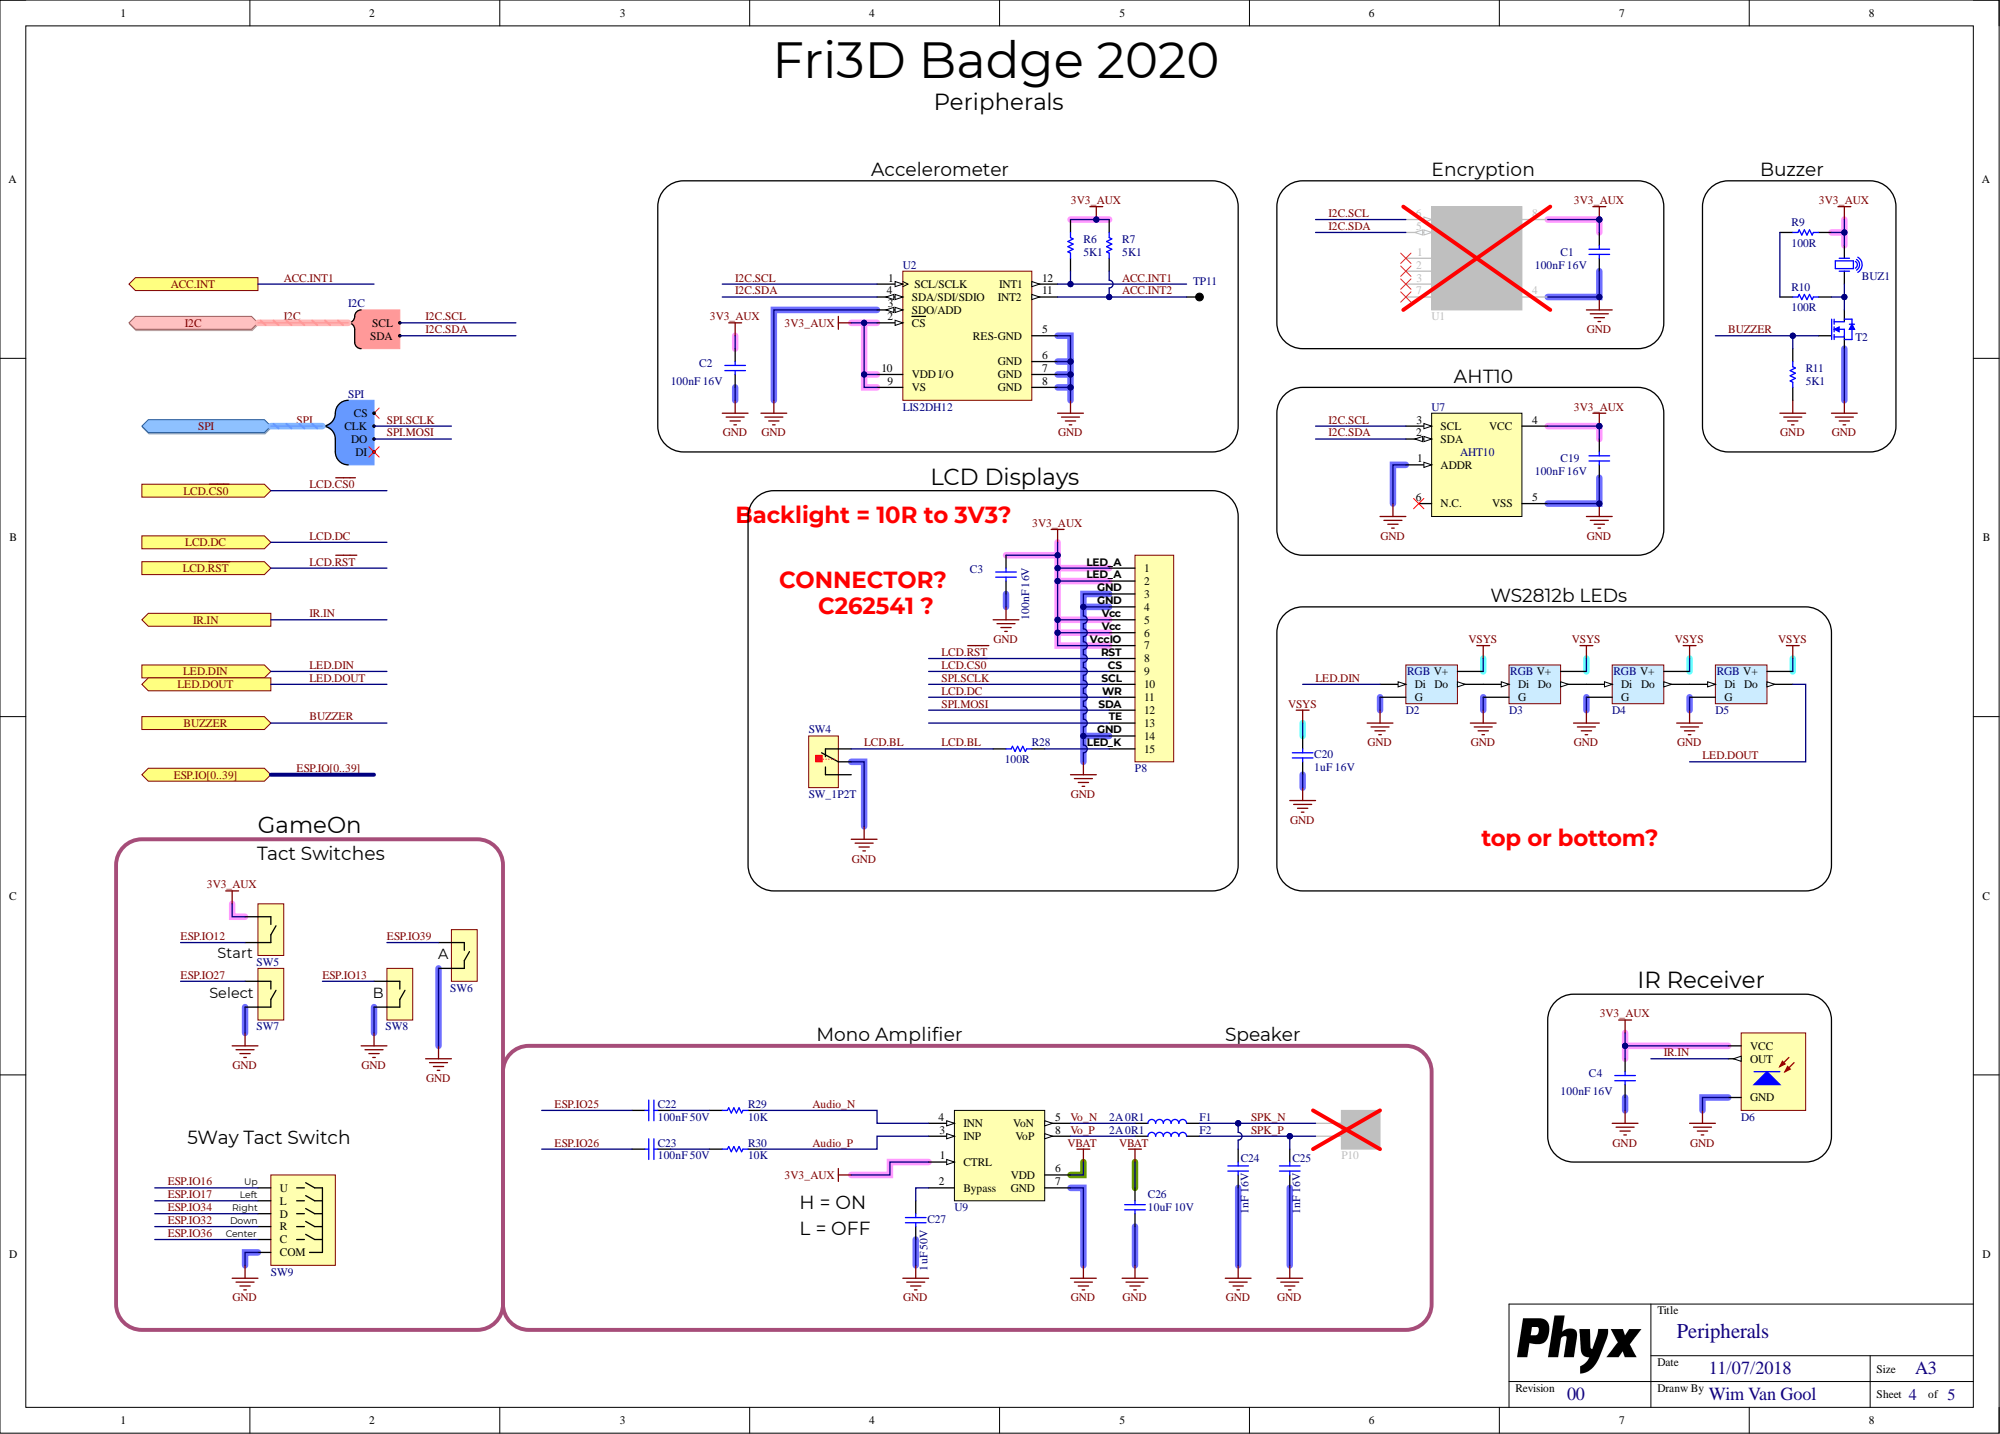
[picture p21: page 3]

LCD.DC

GND
Vcc
VccIO
RST
CS
SCL

SDA
TE
LED_K

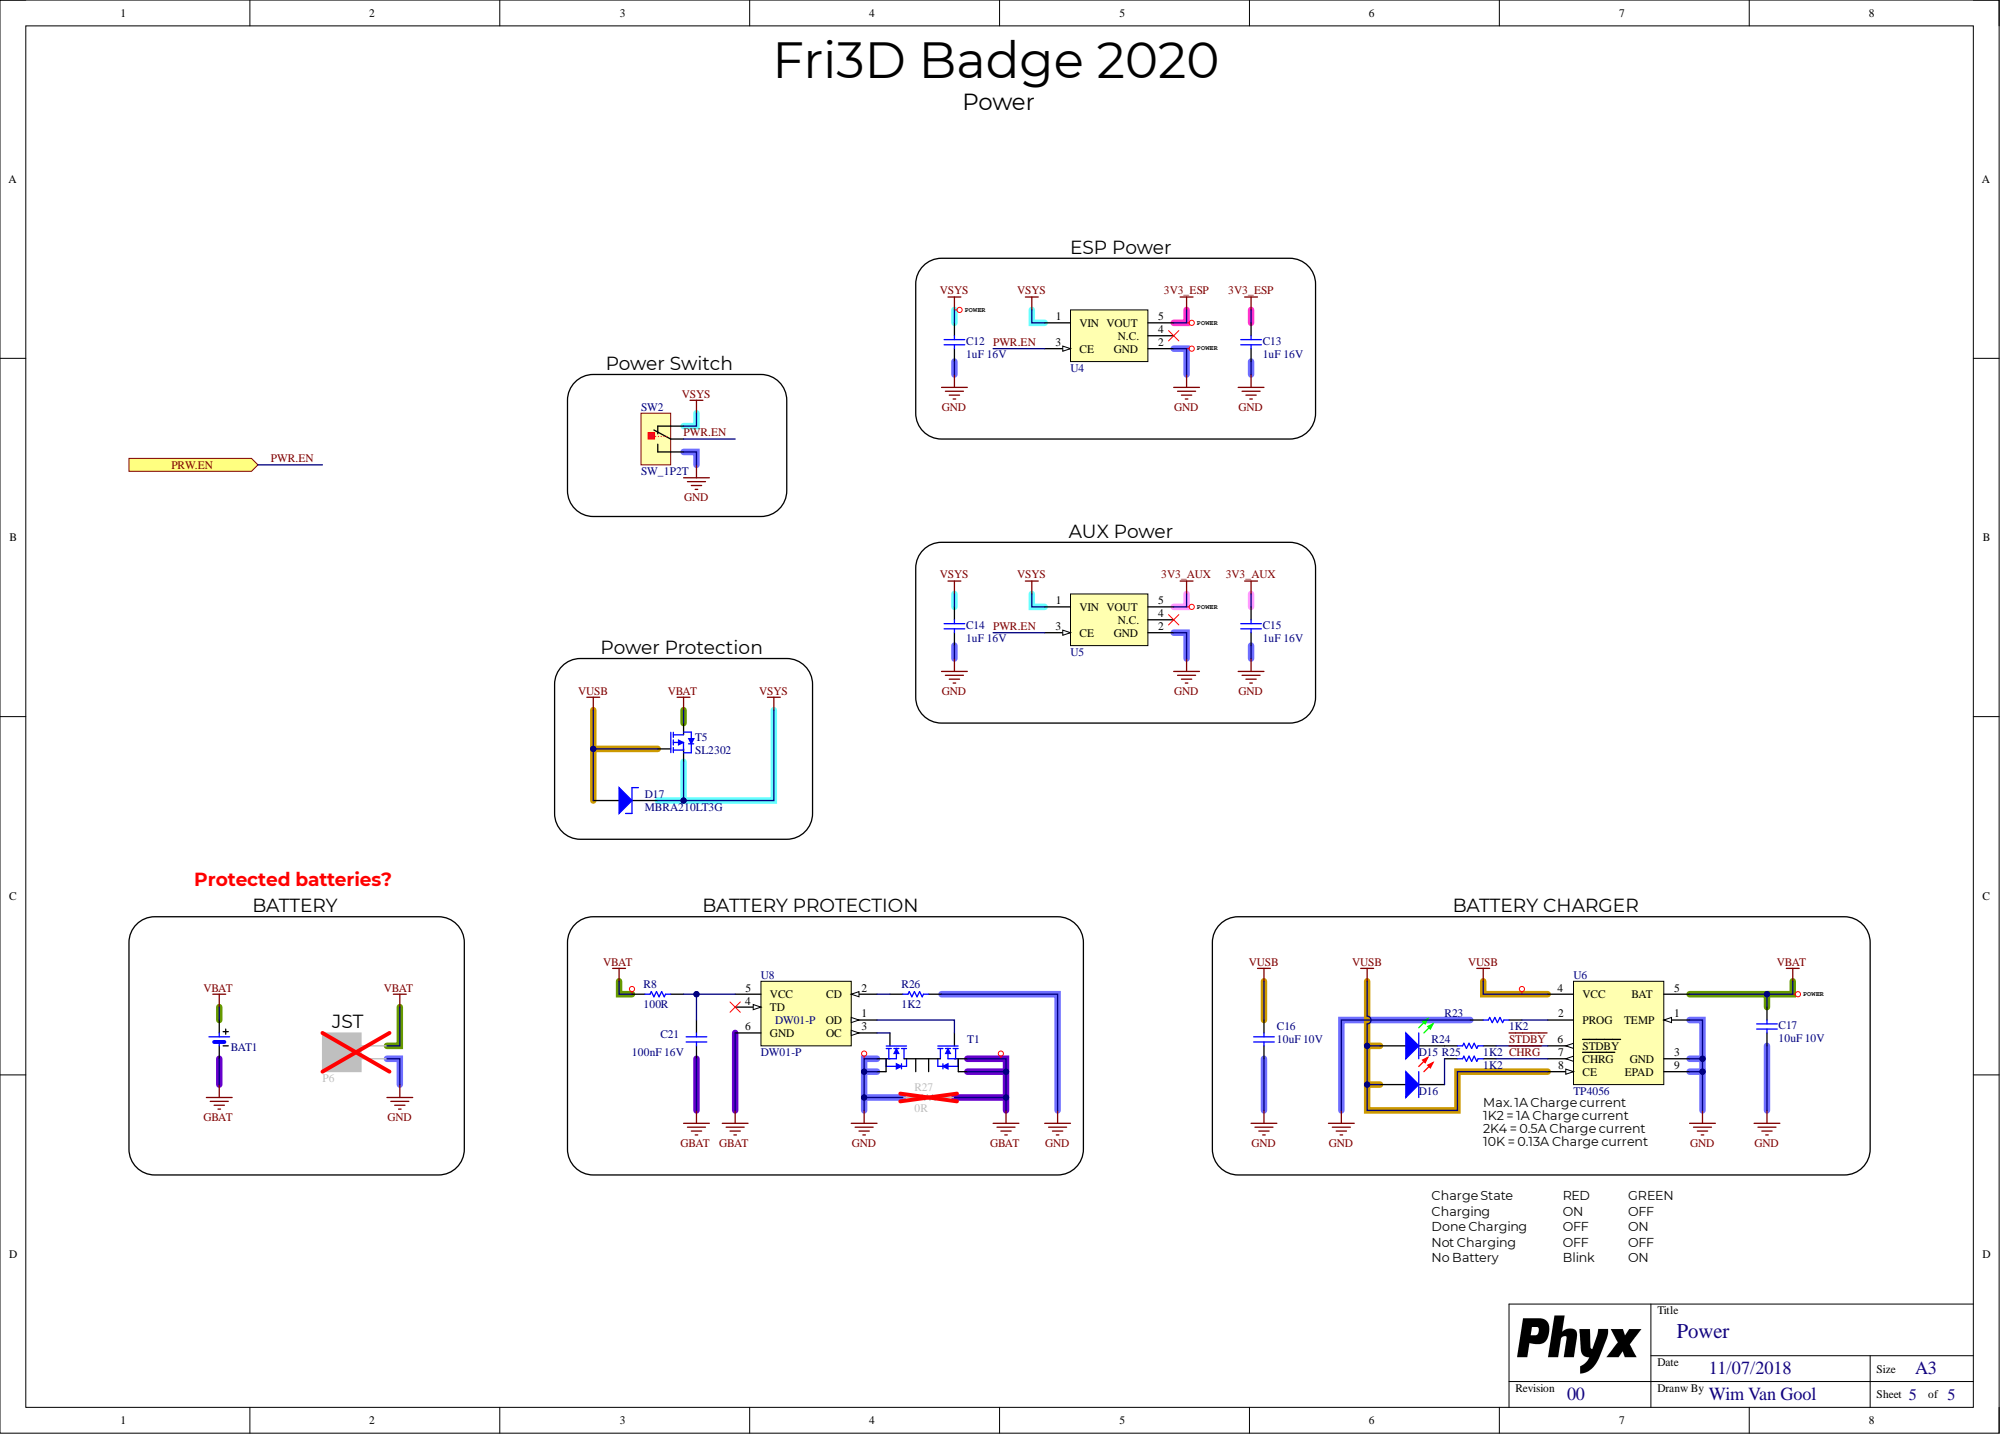
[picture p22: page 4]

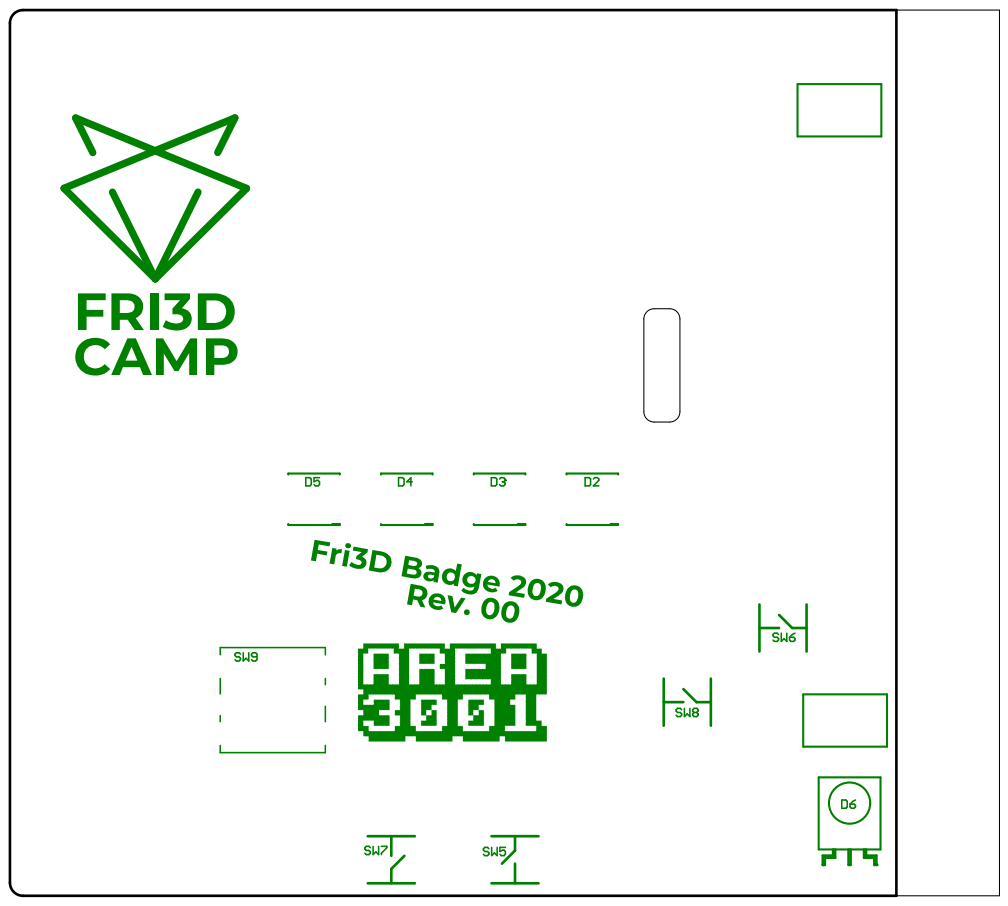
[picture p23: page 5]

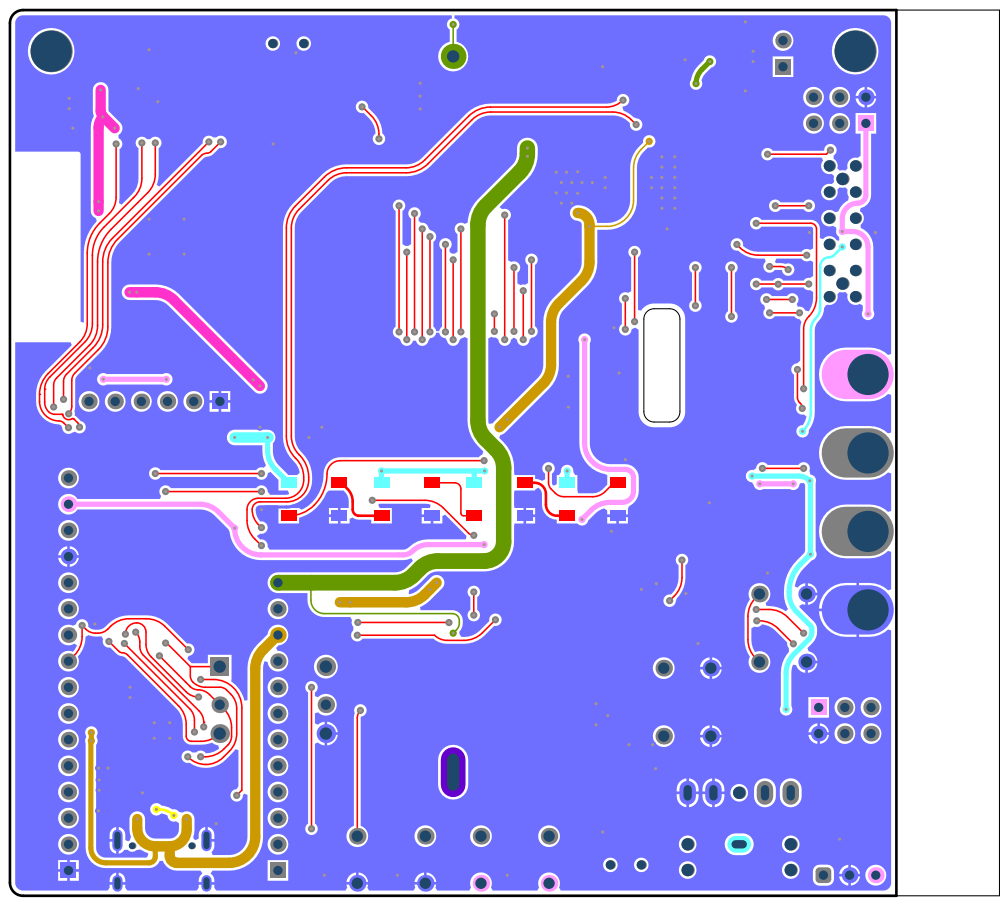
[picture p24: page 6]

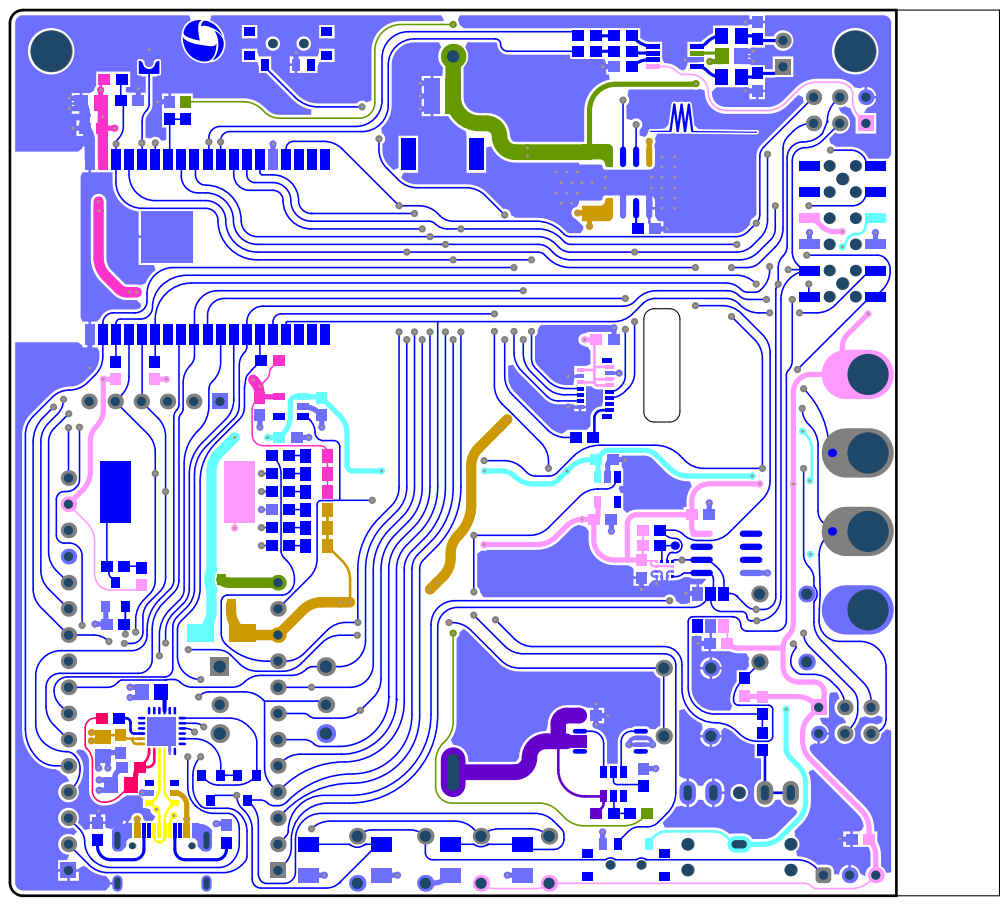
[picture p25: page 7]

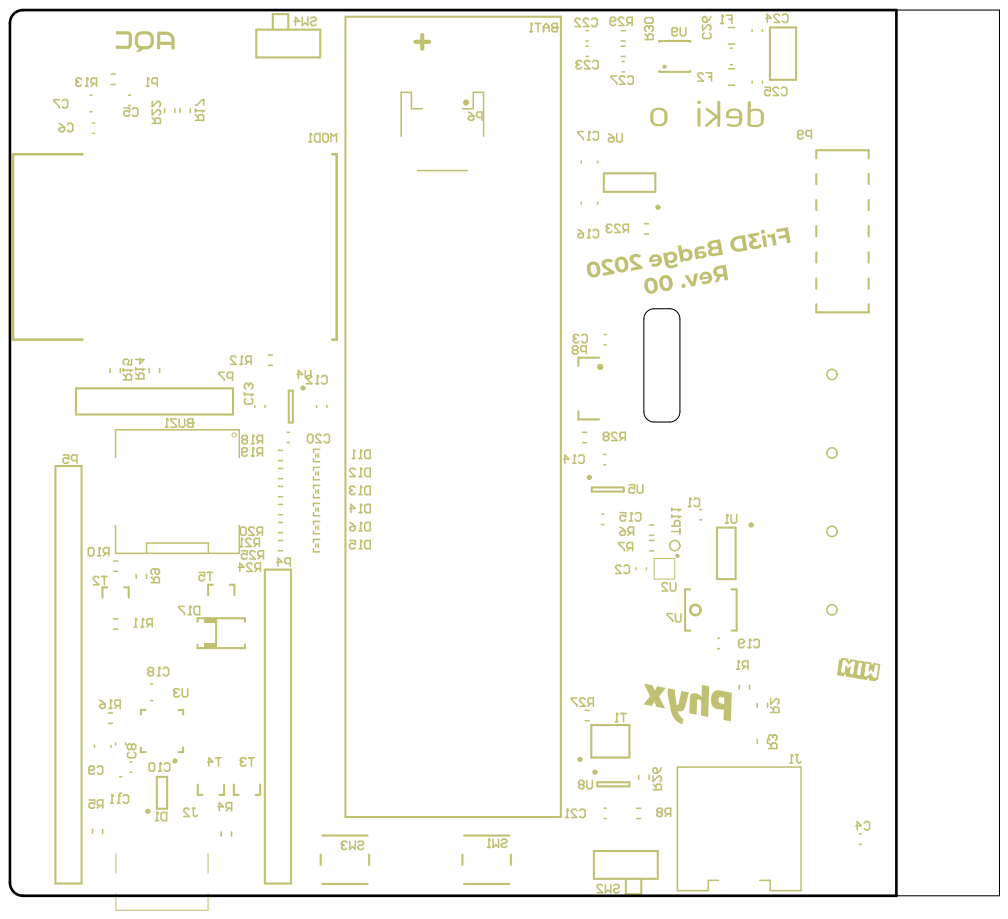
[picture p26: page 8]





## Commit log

2022-02-23 Rev. 00 and 01 design files added
    Added the design files for Rev. 00 and 01
    [Bill of Materials-Fri3D_2020_00(Default).xls, Bill of Materials-Fri3D_2020_01(Default).xls, BoM Full Option-Fri3D_2020_00.xls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]
2022-06-28 Rev.02 and 03 files added
    Added the design and production files for revision 02 and 03
    [Bill of Materials-Fri3D_2020_02(Default).xls, Bill of Materials-Fri3D_2020_02(Default)_ASSY.xls, Bill of Materials-Fri3D_2020_03(Default).xls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]
2022-07-11 Stemma QT mounted by default
    updated the block diagram to reflect changes in the BoM
2022-08-12 Upload pre-compiled firmware and remove code dir
    Current firmware is available at https://github.com/Fri3dCamp/Badge2020_micropython
